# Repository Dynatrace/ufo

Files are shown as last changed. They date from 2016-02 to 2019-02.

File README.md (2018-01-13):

# UFO
### Visual alert/status display for builds, CI, continuous delivery, operations, and more 
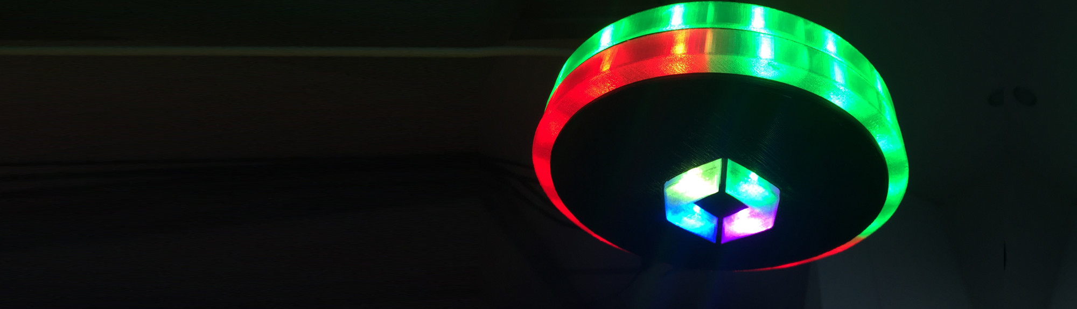
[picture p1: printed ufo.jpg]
printed ufo


* Easy to print, build and 
* Fosters collaboration when placing in areas like office cafeteria, ...
* Open source hard- and software
* WiFi
* REST api, control 34 RGB LEDs
* Integrates with CI/CD/Monitoring (e.g. Jenkins, Nagios, Cloud-Watch, Dynatrace, ...) 
* Easy to modify, Arduino compatible ESP8266 microcontroller 
***

* [__Story__](story) The original UFO was created by Helmut, Dynatrace Chief Software Architect. Read his story.  
* [__QuickStart__](quickstart) Quick guide to configuring the UFO
* [__How to__](howto) Step-by-step instructions for building your own UFO
* [__Parts list__](partlist/readme.md#ufo-partlist)
(folder must use this name for Arduino IDE to automatically upload to ESP8266)
* [__3D printing__](3dprint) folder contains all CAD files plus derivative 3D print files
* [__UFO.ino__](ufo.ino) is the Arduino IDE main program: requires Arduino IDE 1.6.7+ plus additional modules. see ufo.ino source file for more details about requirements
* [__Data__](data) folder contains all files that will be loaded into the ESP8266 flash memory SPIFF drive to contain website data 
* [__Node.js test server__](testserver) contains source files to simulate the ESP8266 webserver for testing purposes; requires Node.js server + static-server module

## No time to print yourself? [Buy a 2nd Gen UFO now](https://www.dynatrace.com/solutions/devops/ufo/get/)

### Example use case at Dynatrace Ruxit
The UFO visualizes the actual continuous delivery pipeline, from developers commit to the build system, all the way to deployments into staging systems. The UFO visualizes two pipeline stages, and for each it uses different color/animation coding to represent states and severity. Of course you can assign your own meanings to the visualization and even customize the UFO and APIs to your needs.
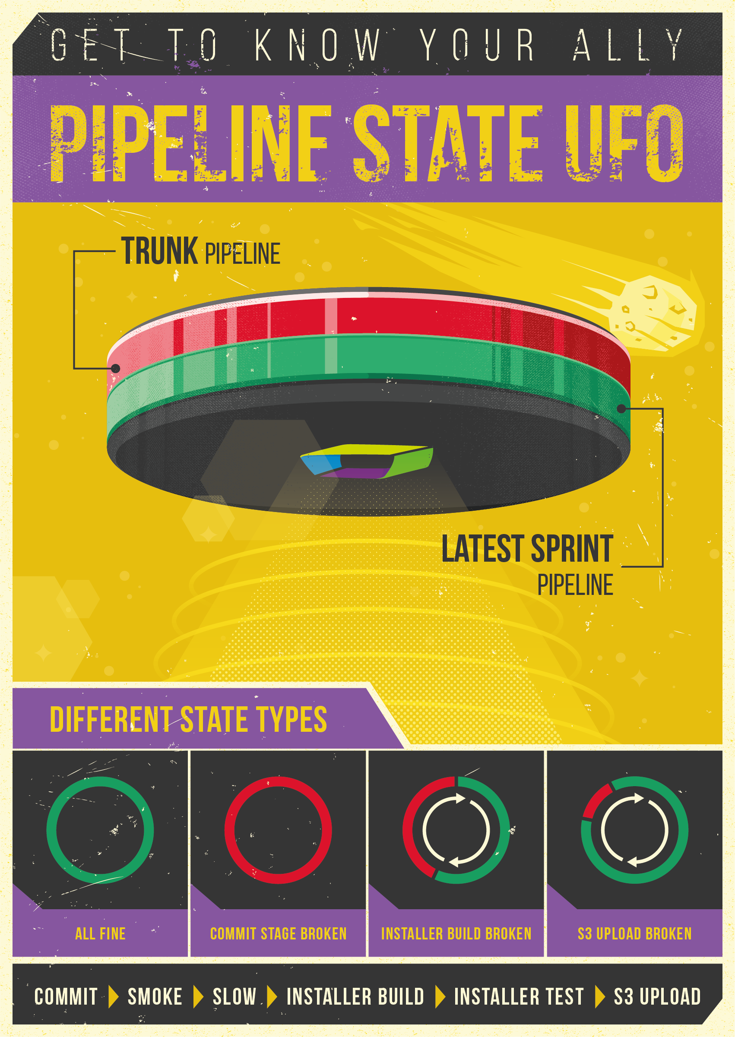
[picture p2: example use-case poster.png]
ufo banner


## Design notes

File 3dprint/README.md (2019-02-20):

# 3D Print your own UFO

You can print your own UFO. All you need to do is order an Adafruit Huzzah, some wires, and print the UFO in black and transparent filament. The Huzzahs ESP8266 hosts wifi and a web server so that REST calls plus a simple hybrid web app are used to configure and control the device.

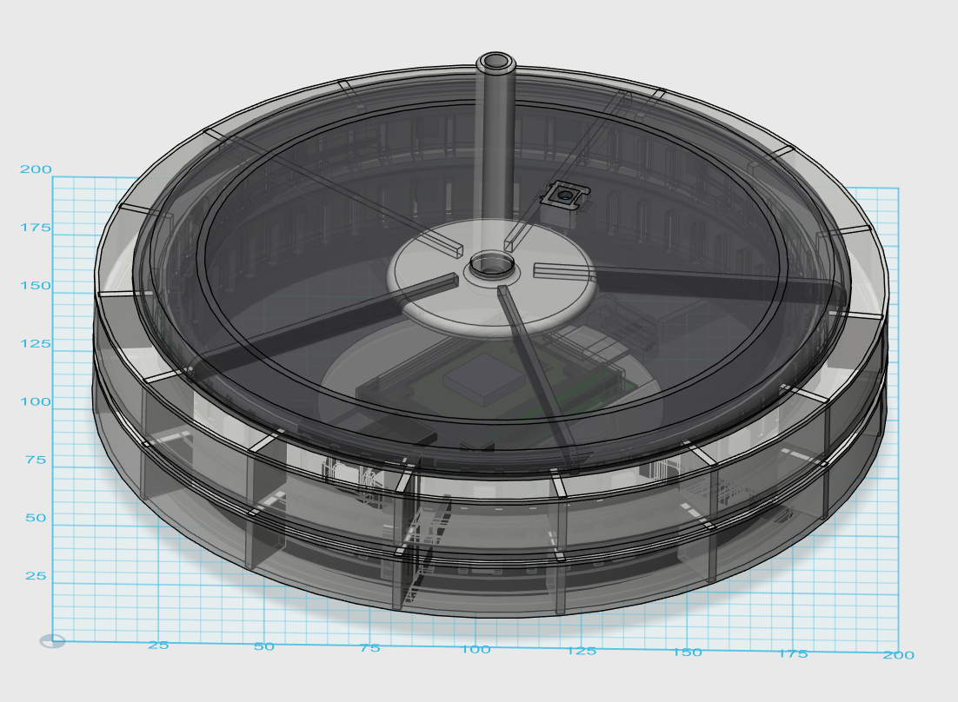
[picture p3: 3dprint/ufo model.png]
UFO model for 3D print


Prints have been tested so far with:
* Makerbot replicator 5th generation
* Ultimaker 2+ (coming soon)

Useful 3D Print guide:
http://www.matterhackers.com/articles/how-to-succeed-when-printing-in-pla

<strong>LIMITED SUPPORT & WARRANTY FOR THE OPEN-SOURCE VERSION OF THE DYNATRACE UFO</strong>

Dynatrace doesn’t provide support, a warranty, or firmware updates for the 3D-printable open-source version of the UFO.

<strong>For all hardware and software support issues</strong>, <a href="https://github.com/Dynatrace/ufo/issues">raise an issue on our GitHub site</a>.

<strong>Firmware updates provided by our user community</strong> are available for <a href="https://github.com/Dynatrace/ufo/tree/master/firmware">download from Github</a>.

DYNATRACE MAKES NO WARRANTY WHATSOEVER WITH RESPECT TO THE GOODS, INCLUDING ANY (A) WARRANTY OF MERCHANTABILITY; (B) WARRANTY OF FITNESS FOR A PARTICULAR PURPOSE; (C) WARRANTY OF TITLE; OR (D) WARRANTY AGAINST INFRINGEMENT OF INTELLECTUAL PROPERTY RIGHTS OF A THIRD PARTY, WHETHER EXPRESS OR IMPLIED BY LAW, COURSE OF DEALING, COURSE OF PERFORMANCE, USAGE OF TRADE OR OTHERWISE.

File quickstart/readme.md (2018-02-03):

# UFO Quickstart

## Power Supply

Connect the UFO to a 2000mA USB charging adapter.
e.g. the iPad or Windows Surface charger should work fine, but check the specs beforehand.
Note that the UFO draws more current than standard USB can provide.
Please be warned! Also note that the USB cable is for power only,
there is no data-connection through it.

The intended use is pendant mounted at the ceiling.
But some geeks use it mobile, so they take it into their office park for example.
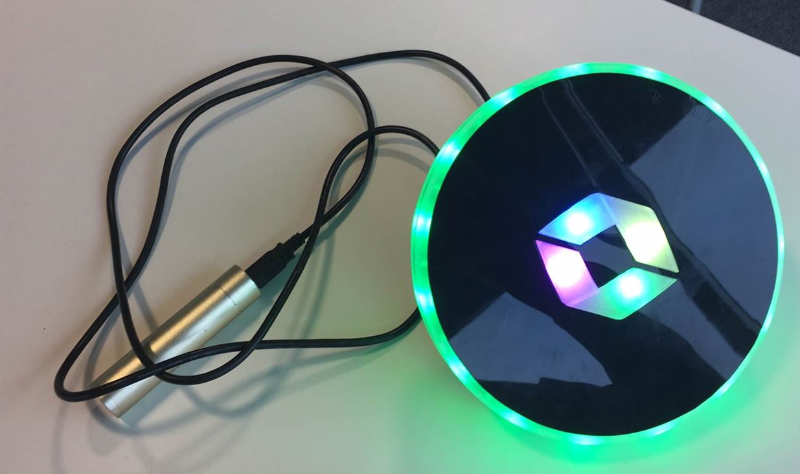
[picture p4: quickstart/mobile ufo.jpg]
mobile ufo


## Check Firmware Version

This description is for [firmware](../firmware) versions dated after 20th of October 2016.
If you have older firmware, please follow the firmware updated procedures in the howto guide.

## Configure Wifi

1. As default and when clicking the hardware reset button at the top of the UFO,
the UFO starts a Wifi access point with an SSID named "ufo".
(if you cannot see the "ufo" SSID, click the wifi reset button) -
the UFO alternates a single blue ring

2. Connect a Web browser enabled device (laptop, tablet, smartphone)
to the UFO's Wifi with the SSID "ufo" and navigate to [http://192.168.4.1](http://192.168.4.1) -
Once connected the UFO blinks with a second blue ring

3. Configure UFO wifi settings so that the UFO connects to your wifi
(Note: WPA2 works well, but enterprise WPA2 and PEAP authentication is not yet available) -
whenever the UFO is trying to connect to your wifi, the UFO blinks yellow.
So you can declare connection success when the yellow stops blinking.

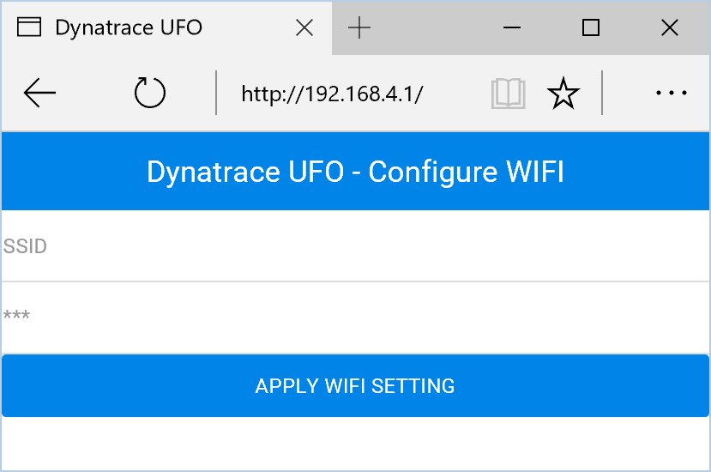
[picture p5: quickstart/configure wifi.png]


Note: If you have troubles using the web UI for setting the wifi config,
you might have more success using the REST API directly:
`http://192.168.4.1/api?ssid=<ssid>&pwd=<pwd>`

Tip: To test and play with the ufo despite enterprise wifi,
or in situations that require a wifi login, you can use following workaround:
e.g. Windows 10 (anniversary update) mobile hotspot feature or connect it your mobile devices hotspot capability.
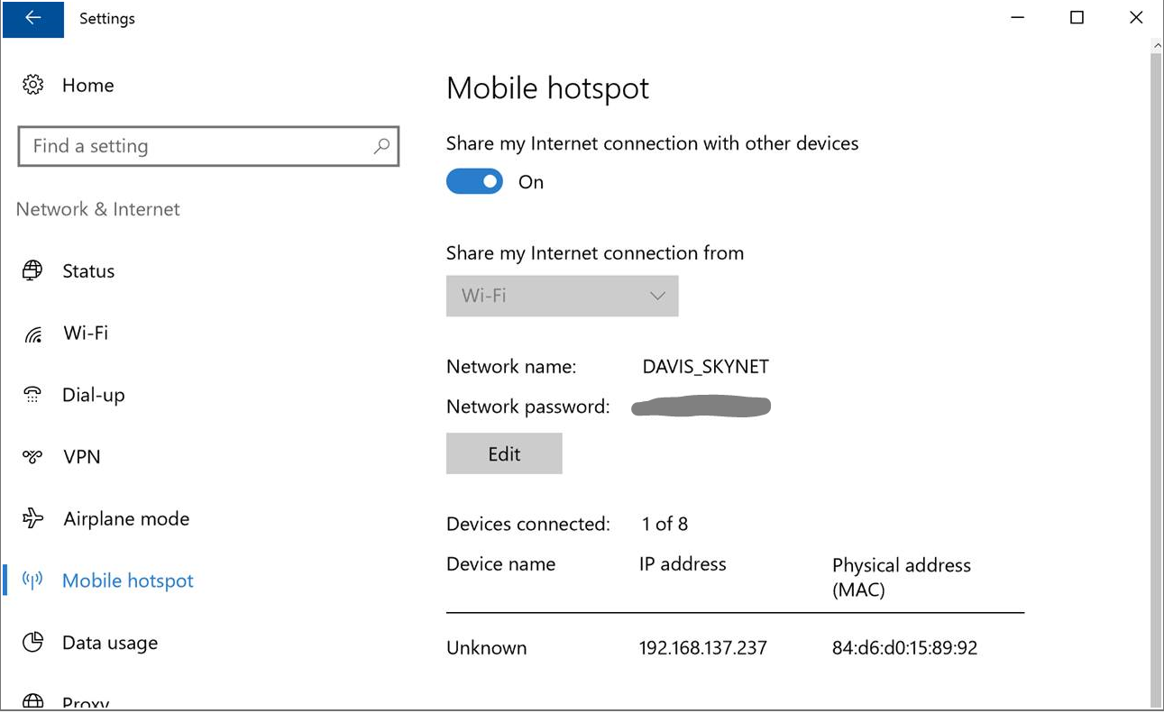
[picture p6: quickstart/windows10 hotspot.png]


1. The UFO will reboot after you configured its Wifi and start to blink
yellow while trying to connect and show color encoded IP address when connected.
At that point you might be able to connect to it with [http://ufo](http://ufo)
as the UFO registers with a default hostname of "UFO"
with the DHCP server.

If that doesnt work you will need to use `http://<ipaddress>`.

There are multiple ways to discover the IP address of the Dynatrace UFO
in case you need it:
  1. Option: the UFO is displaying the address color coded until you access
  it the first time.
  The lower ring visualizes the current IP address digit by digit.
  192.168... will light 1 led then 9 (shown as 5+4 LEDs) then 2 and so on.
  A dot is visualized as 3 white leds.
  The individual digits are separated by a short white flash.
  The IP is visualized over and over again until the first api rest
  call is issued. To stay in sync every IP address visualization
  run uses a different color.
  1. Option: In case you used Windows 10 hotspot,
  you will find the IP address right there.
  1. Option: lookup the MAC address in your Wifi Access Point
 and get the IP address assigned by DHCP.

## Integration with Dynatrace SaaS

The Dynatrace UFO polls the Dynatrace SaaS problem status using HTTPS.
For that you need to create in the Dynatrace SaaS user interface
an access token. (and please don't try to use the token in the screenshot,
its of course an invalid one).
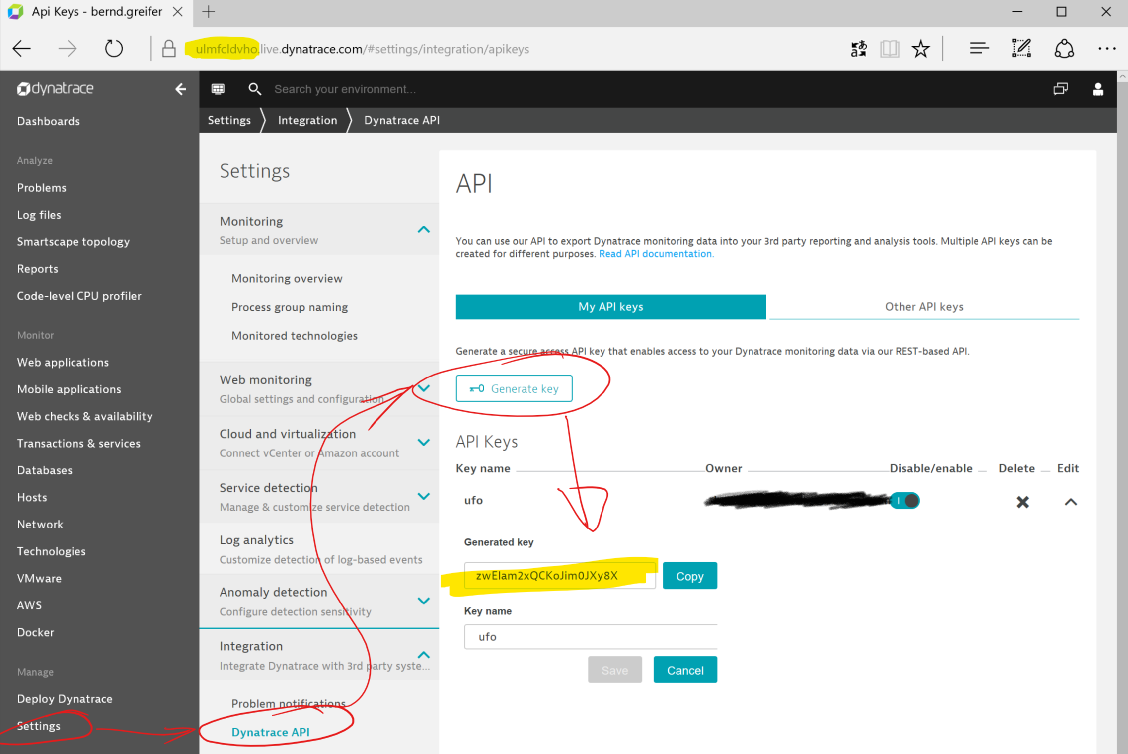
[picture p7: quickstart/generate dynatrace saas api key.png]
generate%20api%20token


Dynatrace SaaS default integration shows currently following color codes
* green: no open problem
* all red: 1 open problem affecting end users
* all purple: 1 open problem affecting services
* all blue: 1 open problem affecting infrastructure only
* 2 or 3 red segments rotating:
2, 3 or more opten problems affecting end users
* 2 or 3 red purple rotating:
1 open problem affecting services.
* 2 or 3 red blue rotating:
1 open problem affecting infrastructure only
* mixtures of above, where use impact where severity is in the order of
user impact, services, infrastructure

This is how it looks when it is connected and showing a problem:
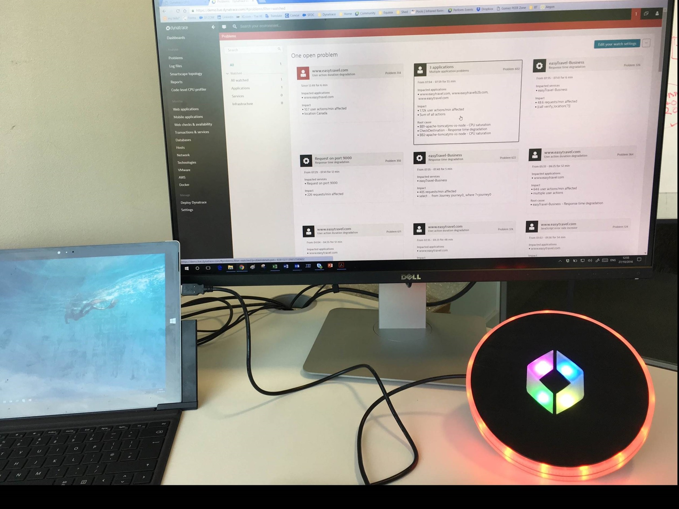
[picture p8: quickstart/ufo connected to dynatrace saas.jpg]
Ufo%20alerting%20of%20live%20problem


## Integration with Dynatrace Managed

Coming soon. This will use webhooks.
Please use the Generic REST interface for now.

## Integration with Dynatrace AppMon

Coming soon. Please use the Generic REST interface for now.

## Generic REST Integration

The UFO's REST API is well documented in [a Dynatrace blog post (Step #2: Using the REST API)](https://www.dynatrace.com/blog/using-dynatrace-devops-pipeline-state-ufo/). However, here are some UFO communication examples (REST calls):

GET `http://<ipaddress>/api?top_init=1&top=0|3|FF0000&top_bg=00FF00`

GET `http://<ipaddress>/api?top_init=1&top=0|1|FFC000|1|3|FF0000|4|1|FFC000&top_bg=00A00a&top_whirl=220`

GET `http://<ipaddress>/api?bottom_init=1&bottom=0|15|FF0000&bottom_bg=0000FF&bottom_morph=500|6`

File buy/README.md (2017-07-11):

# Buy?
If you would prefer to buy a Dynatrace UFO versus build it yourself, 
then you can buy it here:

https://www.dynatrace.com/solutions/devops/ufo/get/
please note that this includes the more powerful ESP32 microcontroller, dual-core with Wifi and bluetooth.

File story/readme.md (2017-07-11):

# The Dynatrace UFO story

*Bernd:* Hi Helmut, you have invented the UFO, a multidimensional state visualization device, for Dynatrace to improve our agile development, build and continuous delivery processes. 
So what exactly is the UFO and what motivated you to create it?

__Helmut:__ I created the UFO because we had a lack of awareness of build problems in our CI process. 
It often happened that developers broke the pipeline without realizing it. Without knowing that they'd introduced a problem into the pipeline they had no reason to consider that their recent changes might be the cause of a problem. 
Installing this visualization device in our cafeteria made a big change in our developers' awareness of build failures, and also in their mindset. Pipeline errors need to be avoided at all cost – you don’t want to be the one who floods the cafeteria with red light.

So generally stated, the UFO is a general state visualization device. The requirement to function from any view angle gave it its distinctive UFO design. It consists of 2 layers that emit light with customizable color and animation. For us, it provides real-time feedback on our build and continuous delivery process to keep the team in sync and responsible.

*Bernd:* How did it change the behavior of the team?

__Helmut__: The team has become more sensitive to checking the UFO before going home. When the UFO goes red in the cafeteria, devs who recently checked in code now double-check the build results and their inbox where issues are routed to. 

*Bernd:* As our team has hundreds of engineers, one can impact many, right? 

__Helmut:__ Build failures and consequently the red state of the build pipeline not only block all developers from committing their changes but it also delays the build entering the various automated test-stages. This slows down the overall development process and diminishes our productivity.

A fast pipeline is especially crucial in our DevOps environment as we require that potential fixes be brought into production as quickly as possible. Optimal utilization of automated test-resources is an important factor for us, as well.

*Bernd:* The UFO, with its more than 34 individual controllable RGB LEDs, is more powerful than a classic "red alert" lamp. So how is it integrated with the continuous delivery process?

__Helmut:__ The UFO is directly fed with the pipeline state by our quickbuild server at the end of every run via a simple REST interface. One layer of the UFO visualizes the trunk pipeline while the other shows the sprint pipeline state. The DevOps team controls the UFO using Dynatrace Application Monitoring / UEM and Ruxit interfaces. But of course, you can control it from any software capable of performing REST calls.

*Bernd:* We had several top customers who came to our office ask for such an UFO. Since you have built it yourself, what can we tell customers who want to build one themselves? Here are pictures of the original so everyone can see what I am talking about:
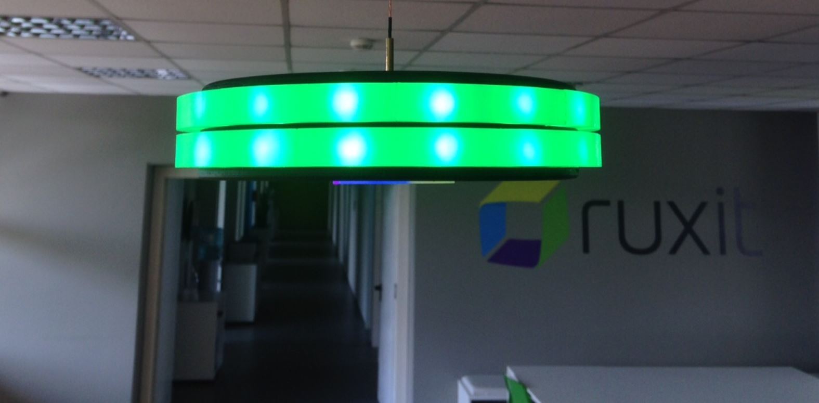
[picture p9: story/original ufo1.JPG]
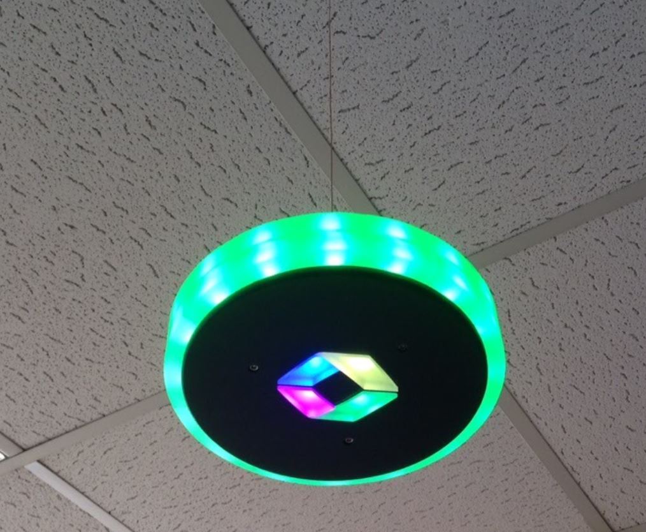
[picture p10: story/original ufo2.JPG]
 

__Helmut:__ Oh, yes. The original version used Raspberry PI and multiple PIC microcontrollers that I'd used in plenty of other projects. To reduce the total number of parts, we designed an open-source version of the UFO that is easily printable on a standard 3D printer and a single ESP8266 wifi microcontroller. The total cost is in the range of $80 including the wifi-enabled electronics. It's available at https://github.com/Dynatrace/ufo

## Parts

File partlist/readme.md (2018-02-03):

# UFO partlist

## Approximate cost per UFO
* $5 filament (filament spools cost $20 to $65, and you need two colors)
 * black PLA filament
 * transparent PLA filament
* $35 for microcontroller, USB cable, switch and wires
* $10 for 2000mA USB charging device to power the UFO

## What you'll need
* 3D printer capable of printing volume L19cm x W19cm x H12cm minimum
* soldering iron, wires
* FTDI cable (approx $15) for programming the ESP8266

## Places to look for the electronics
* U.S.: Adafruit <http://www.adafruit.com>
* U.S./Internationally: Mouser electronics <http://mouser.com> (they have many international sites such as mouser.de, mouser.at, ...)
* Germany/Austria: Flikto <http://flikto.de>
* Germany/Internationally: EXP Tech <https://www.exp-tech.de/>

## Electronics partlist
* 1x [Adafruit Huzzah ESP8266 breakoutboard](https://www.adafruit.com/products/2471) 
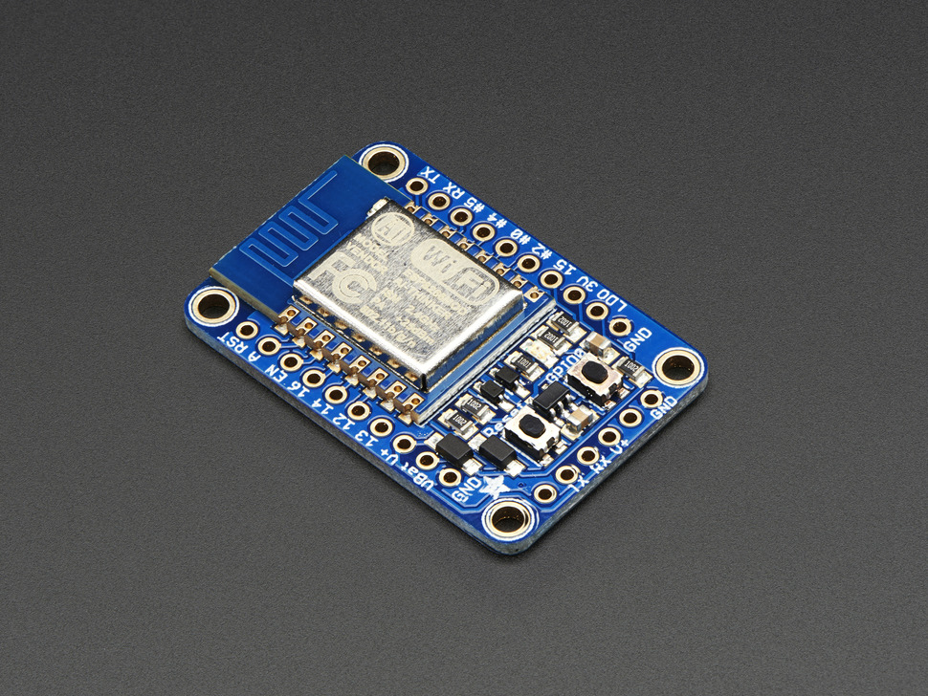
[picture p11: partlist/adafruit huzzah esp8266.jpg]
Adafruit Huzzah breakout board

* 2x meters [Adafruit DotStar Digital LED Strip, 30 LED per meter](https://www.adafruit.com/products/2237)
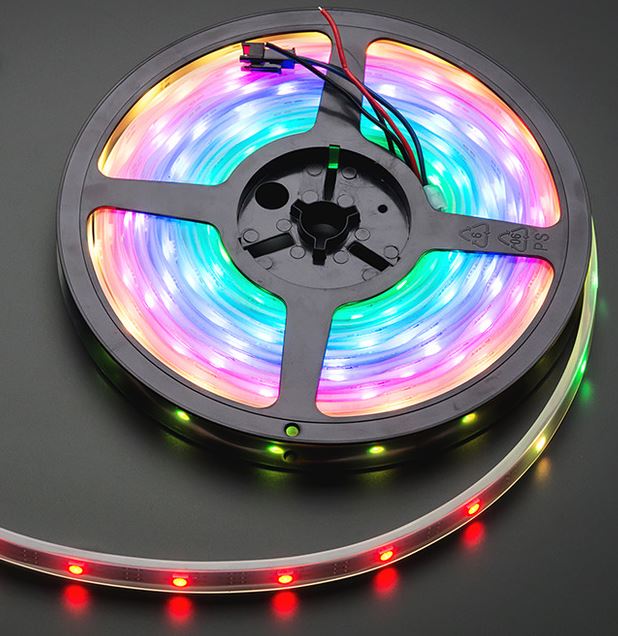
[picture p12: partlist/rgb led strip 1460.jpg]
LED strips 800MHz

* 1x [mini-push-button-switch 6x6mm](https://www.sparkfun.com/products/97)   
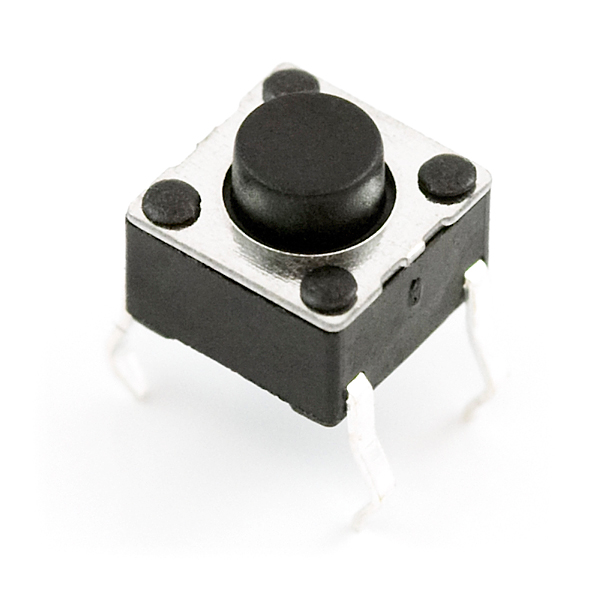
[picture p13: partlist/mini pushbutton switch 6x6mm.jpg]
mini pushbutton switch
 
* 1x [USB cable to power the ufo] e.g. (https://www.sparkfun.com/products/512) but note, the cable must be able to handle the current of up to 2A; and we will clip off one of the plugs 
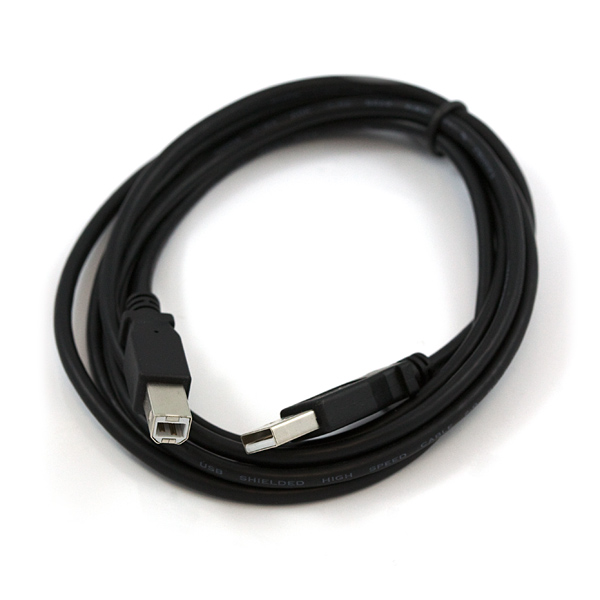
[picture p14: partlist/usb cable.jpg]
USB cable

* If you don't have it yet, you will need this cable for programming [Sparkfun FTDI 5V with 3.3V IO cable](https://www.sparkfun.com/products/9717) 
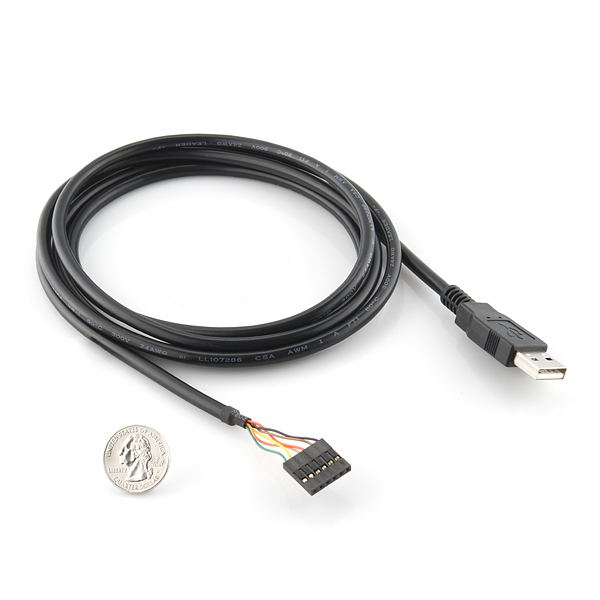
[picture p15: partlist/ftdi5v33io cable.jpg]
FTDI cable


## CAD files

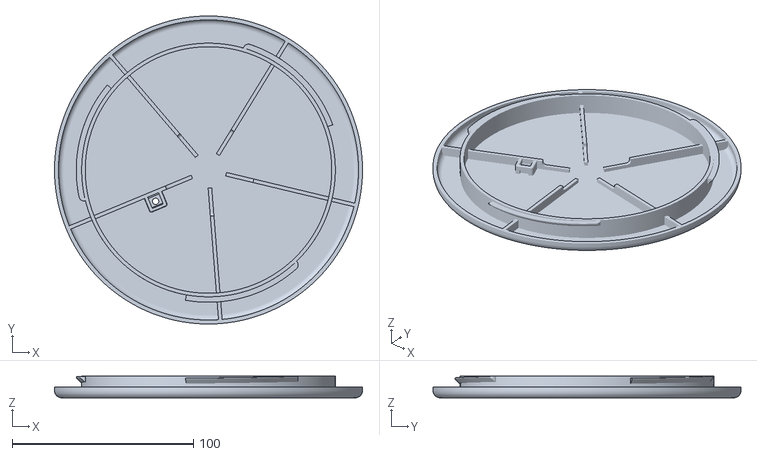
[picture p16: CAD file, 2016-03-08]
3dprint/printfiles v3/top.stl
170.0 x 170.0 x 12.0

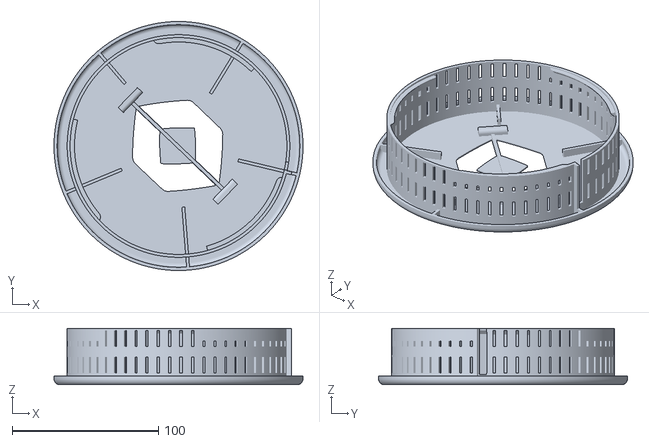
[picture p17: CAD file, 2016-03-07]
3dprint/printfiles v3/bottombuildup.stl
170.0 x 170.0 x 38.5

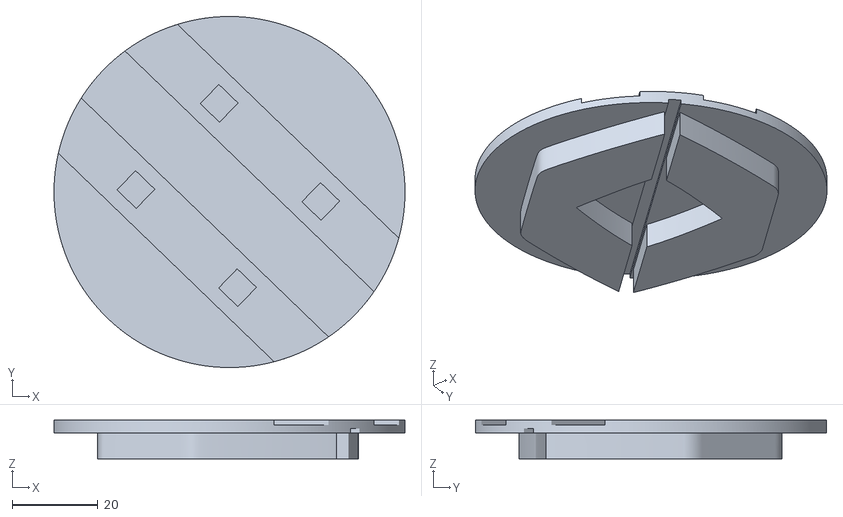
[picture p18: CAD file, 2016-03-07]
3dprint/printfiles v3/downlight inlay.stl
82.0 x 82.0 x 9.02

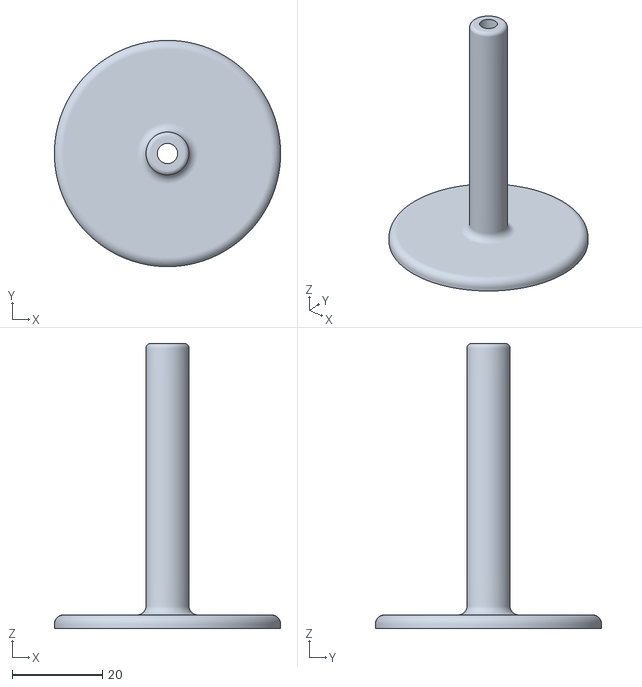
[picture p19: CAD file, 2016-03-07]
3dprint/printfiles v3/cablestabilizer 4.5mm.stl
50.0 x 50.0 x 63.0

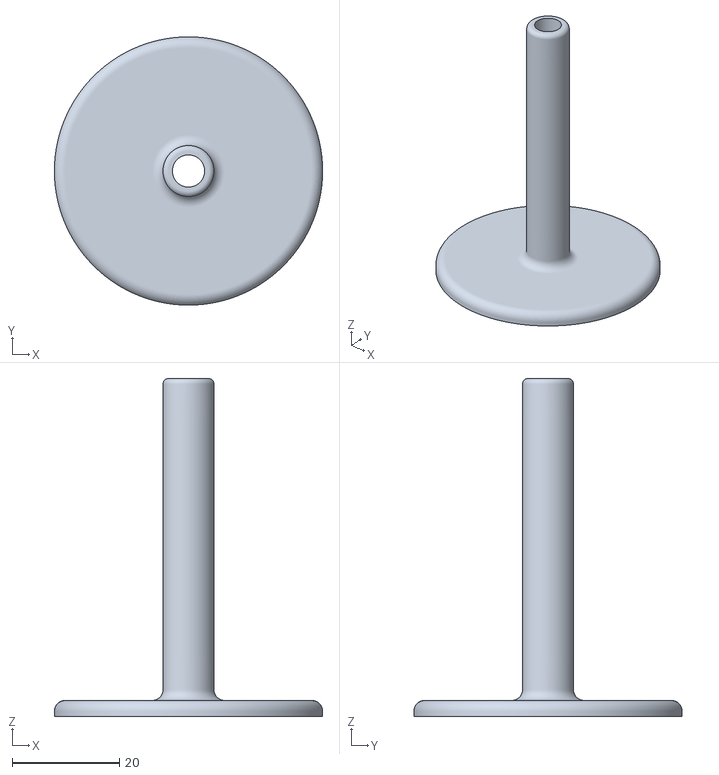
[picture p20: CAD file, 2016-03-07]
3dprint/printfiles v3/cablestabilizer 6.0mm.stl
50.0 x 50.0 x 63.0

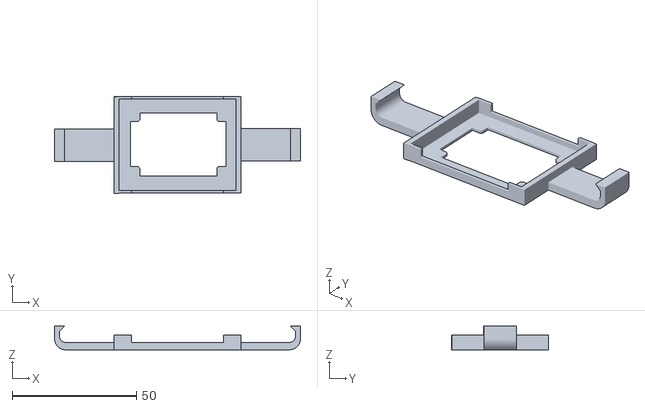
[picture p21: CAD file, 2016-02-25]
3dprint/printfiles v3/huzzahclip.stl
99.0 x 39.2 x 9.50

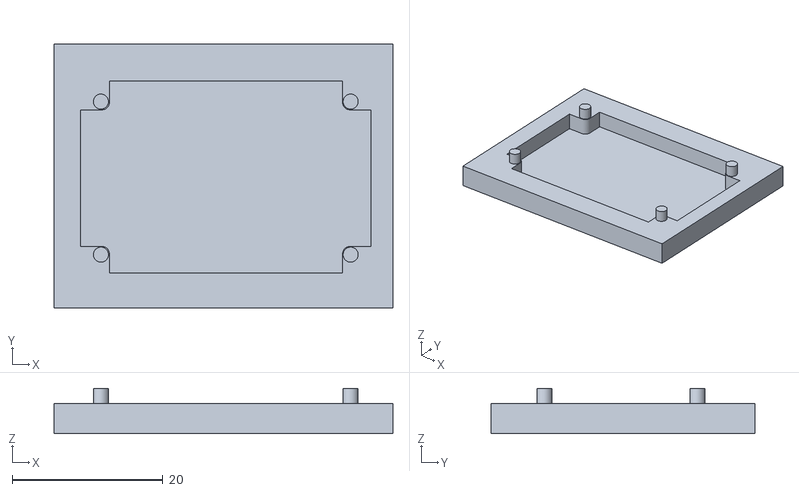
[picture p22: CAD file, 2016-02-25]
3dprint/printfiles v3/huzzahbase.stl
45.0 x 35.0 x 6.00

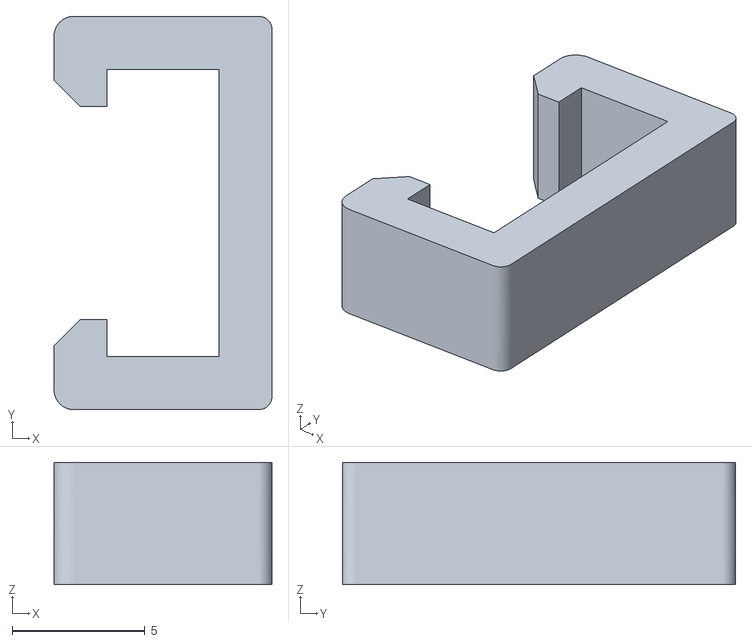
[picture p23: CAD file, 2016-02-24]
3dprint/printfiles v3/minibuttonclip.stl
8.20 x 14.8 x 4.60

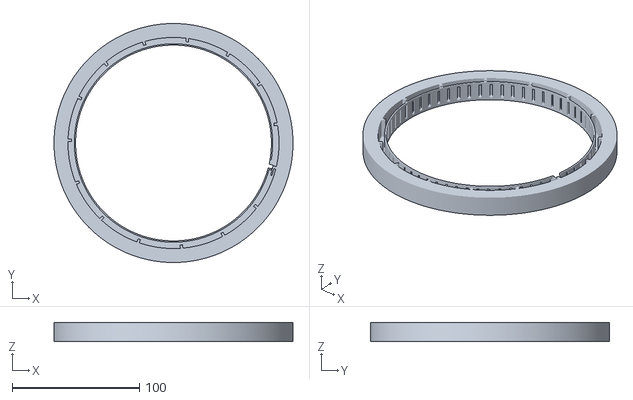
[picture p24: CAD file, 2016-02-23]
3dprint/printfiles v3/ledring.stl
188.0 x 188.0 x 15.0

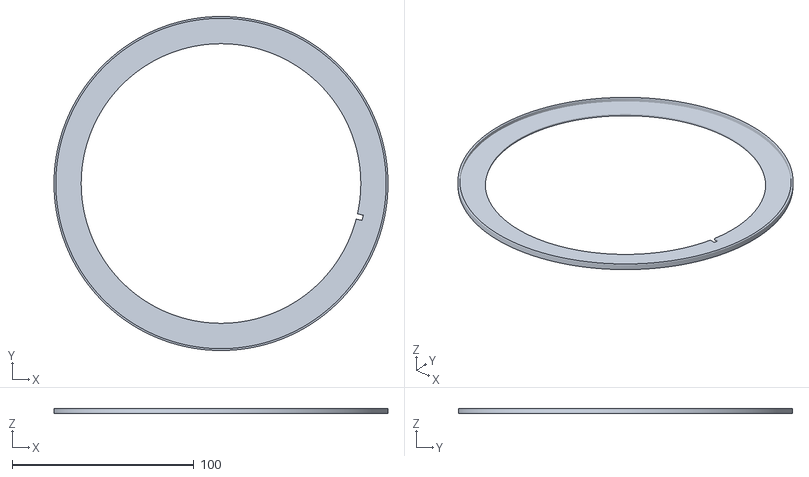
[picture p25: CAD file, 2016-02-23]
3dprint/printfiles v3/separatorring.stl
184.0 x 184.0 x 3.00

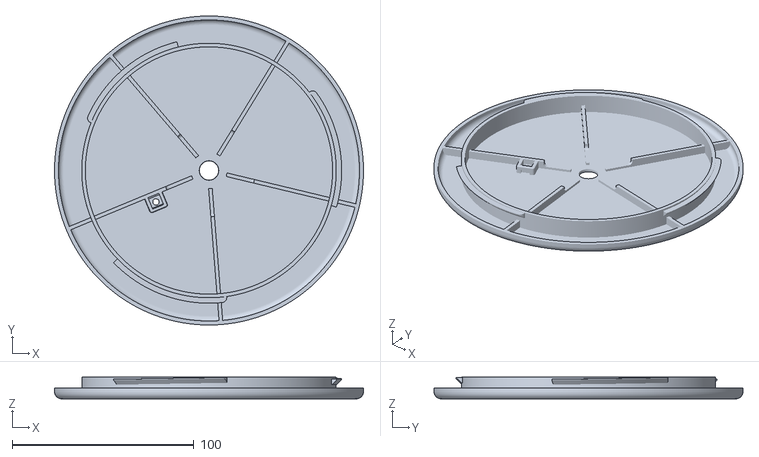
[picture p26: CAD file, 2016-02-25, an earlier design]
3dprint/printfiles v2/top.stl
170.0 x 170.0 x 12.0

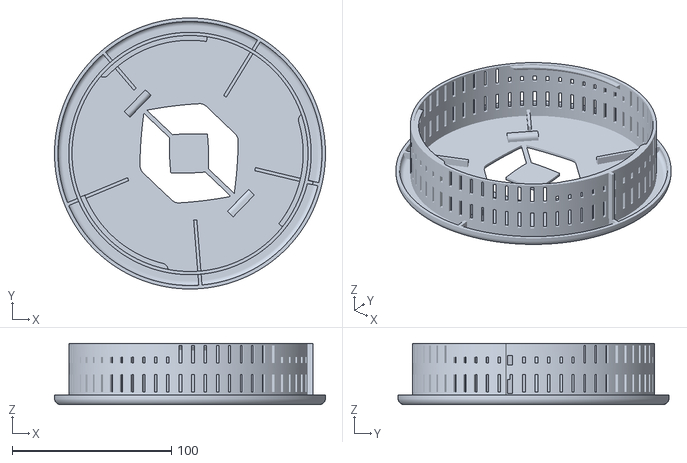
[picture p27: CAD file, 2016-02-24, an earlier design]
3dprint/printfiles v2/bottombuildup.stl
170.0 x 170.0 x 38.5

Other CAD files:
3dprint/printfiles v3/cablestabilizer 5.0mm.stl
3dprint/printfiles v2/downlightinlay.stl
3dprint/printfiles v2/cablestabilizer.stl

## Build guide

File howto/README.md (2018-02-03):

# Instructions for building the Dynatrace UFO

see also [partlist](../partlist)

## Print the 10 pieces in 5 batches

#### We printed using with following settings:
* No supports
* 3 shells
* 0.2 mm layer height (0.1 mm layer worked well too)
* 20% infill

#### 1. UFO case base + microcontroller holder, plus microcontroller clip

black filament
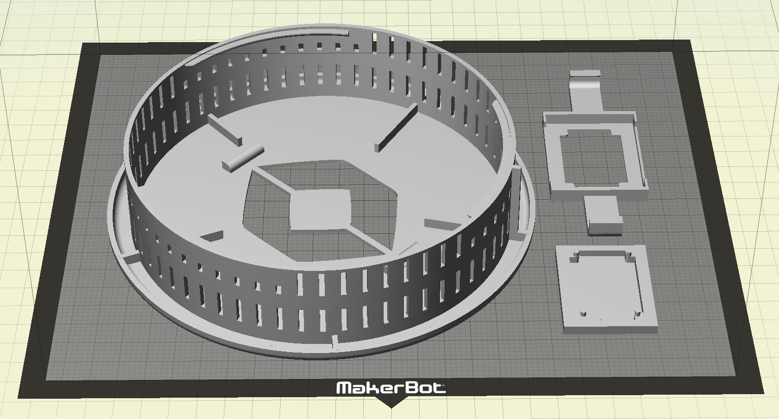
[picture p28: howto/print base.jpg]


#### 2. UFO case top + cable stabilizer + mini-switch-clip

black filament
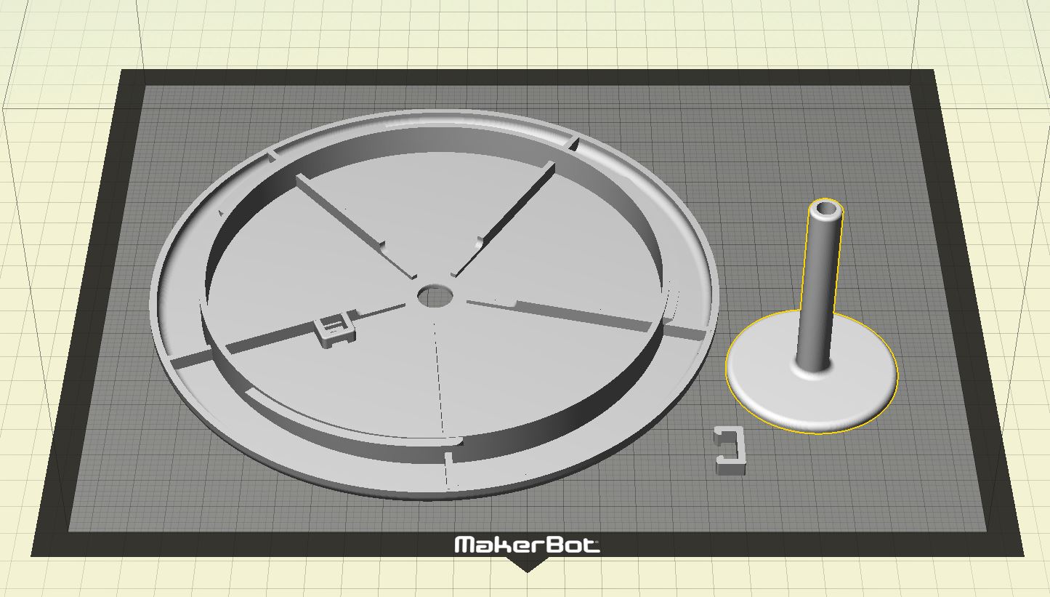
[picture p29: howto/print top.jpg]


#### 3. Separator ring

black filament
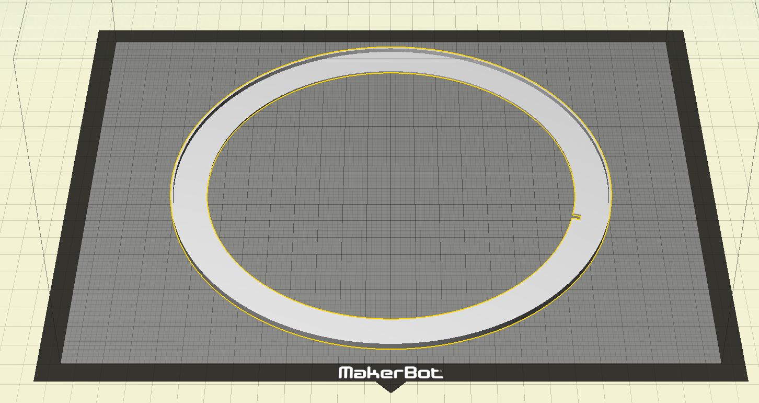
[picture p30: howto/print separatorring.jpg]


#### 4. Downlight inlay + first ring

transparent filament
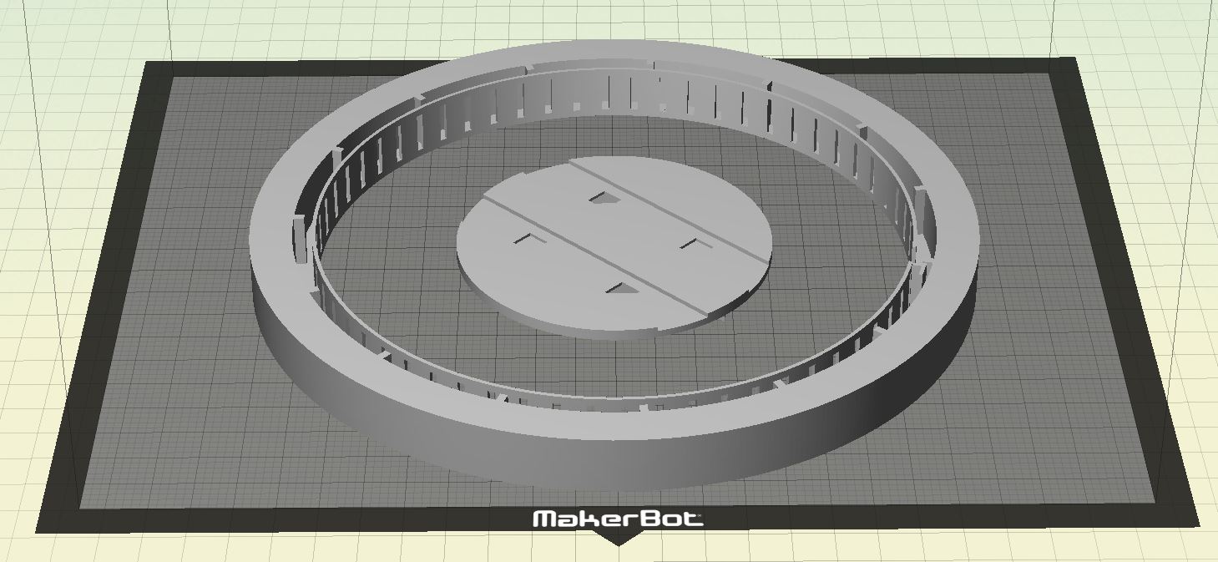
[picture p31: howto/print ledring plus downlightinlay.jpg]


#### 5. Second ring

transparent filament
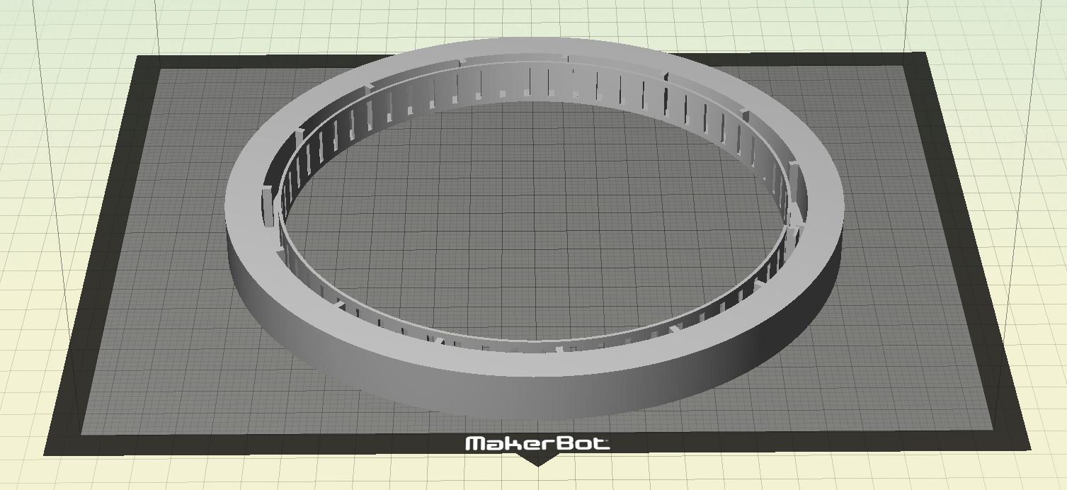
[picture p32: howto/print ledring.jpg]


##  How it all fits together
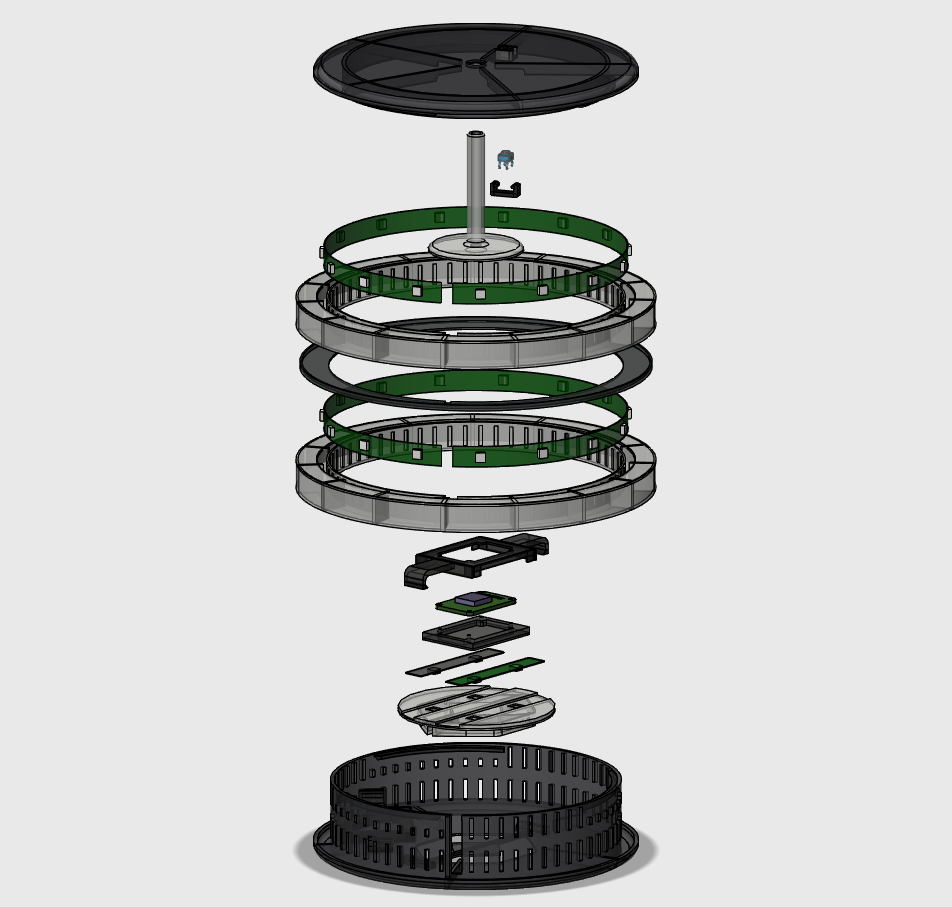
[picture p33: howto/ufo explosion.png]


## Prepare USB cable
Cut off one end of the USB cable and use the 5V line (red) and ground (black) wire for powering the LED strips as well as the Huzzah ESP8266 microcontroller. Make sure to isolate the other wires to make sure you don't damage the USB source or get in contact with the other electronics.
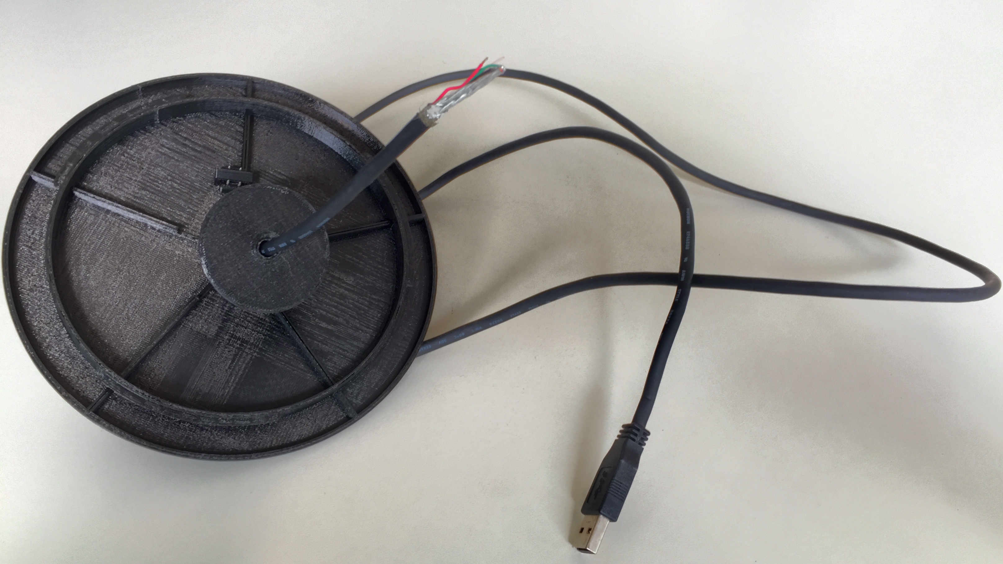
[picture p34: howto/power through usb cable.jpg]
Power through USB cable


## Prepare LED strips
Cut the LED strip into 2 strips of 15 LEDs each and 2 strips of 2 LEDs each. Be sure to cut exactly in the middle of the soldering tabs because you will need to solder cables together here later.
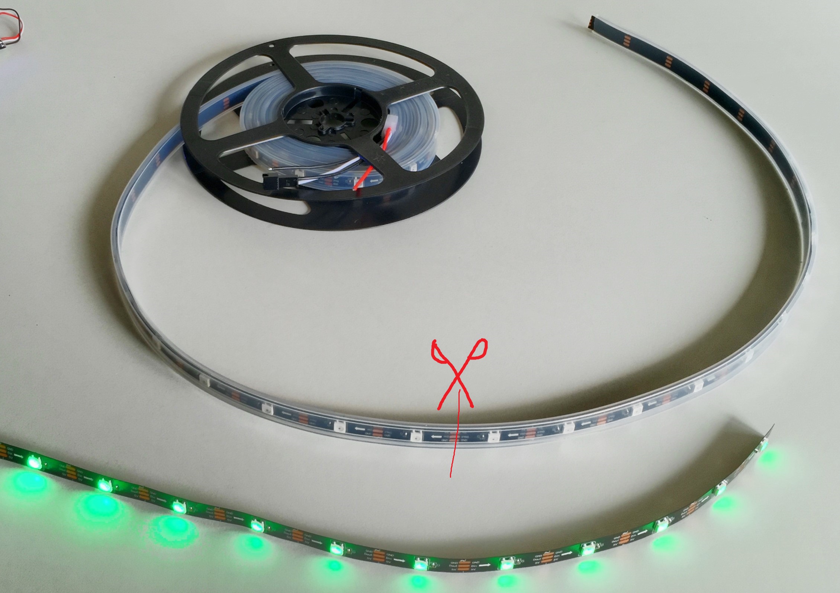
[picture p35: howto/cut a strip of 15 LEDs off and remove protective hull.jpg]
Cut the LED strip in pieces

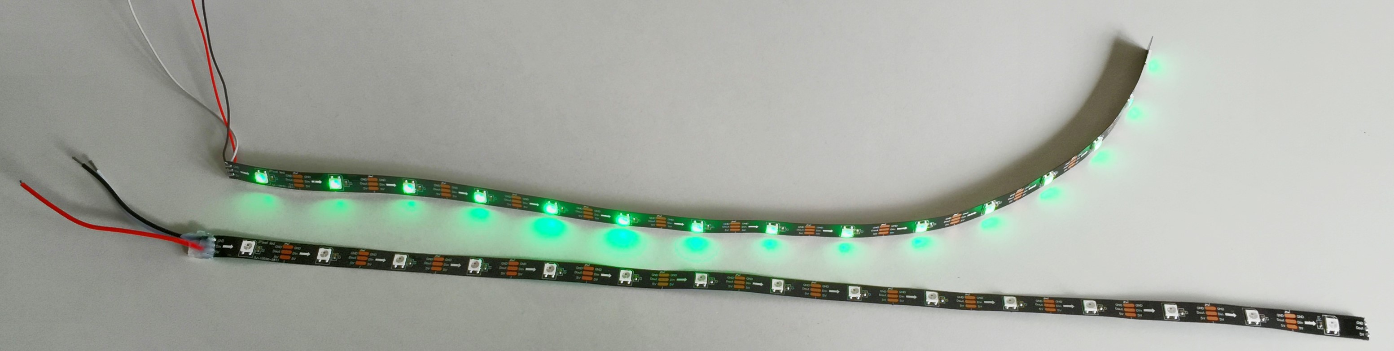
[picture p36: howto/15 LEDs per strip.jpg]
15 LEDs per long strip


## Solder short strips
Solder the short strips in a series accordingly to the data-flow direction. There are arrows on the strip that show you the direction. Data for controlling the bus of LEDs flows from the microcontroller outbound in direction of arrow.
(Note: image still shows 3-pin led strip, but we switched to 4-pin DotStar LED strips)
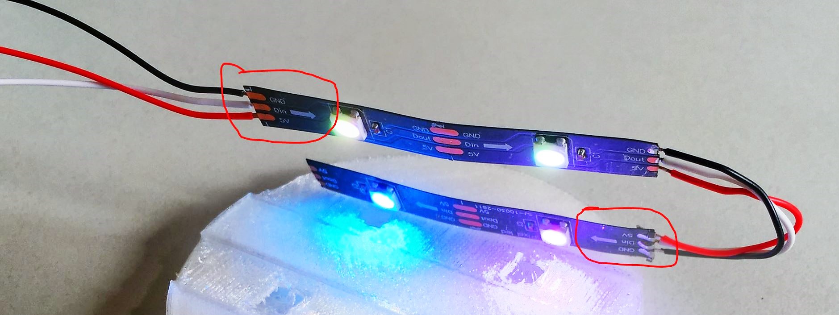
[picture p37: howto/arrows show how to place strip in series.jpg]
Short LED strips soldered in series

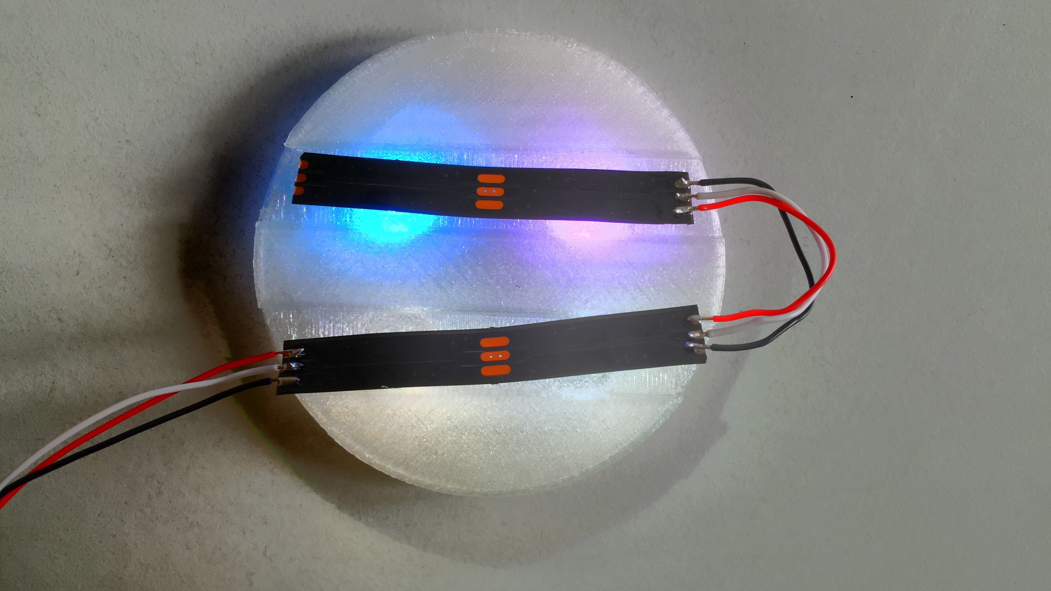
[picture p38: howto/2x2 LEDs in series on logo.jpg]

The DotStar LED strips use 4 wires
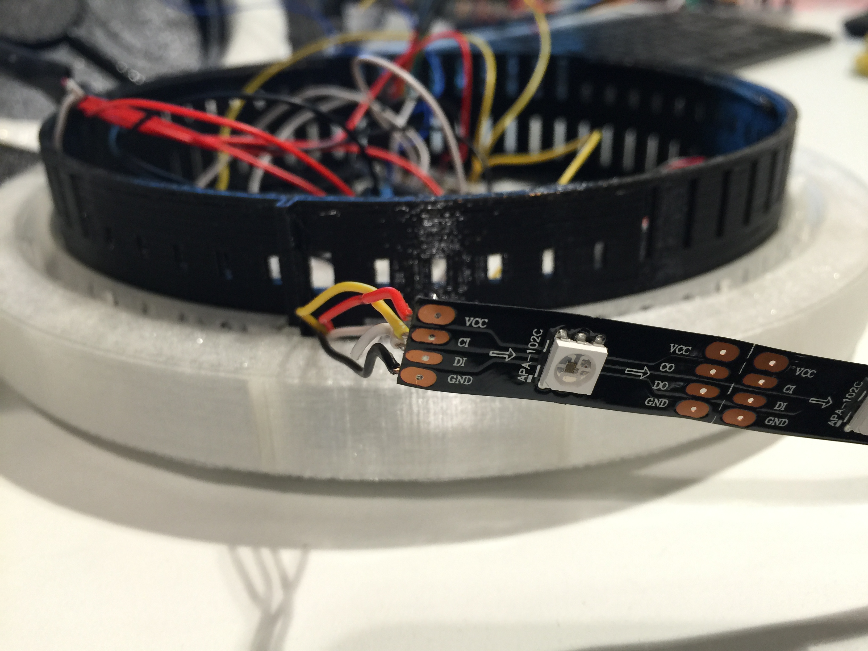
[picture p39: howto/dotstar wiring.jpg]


## Wiring
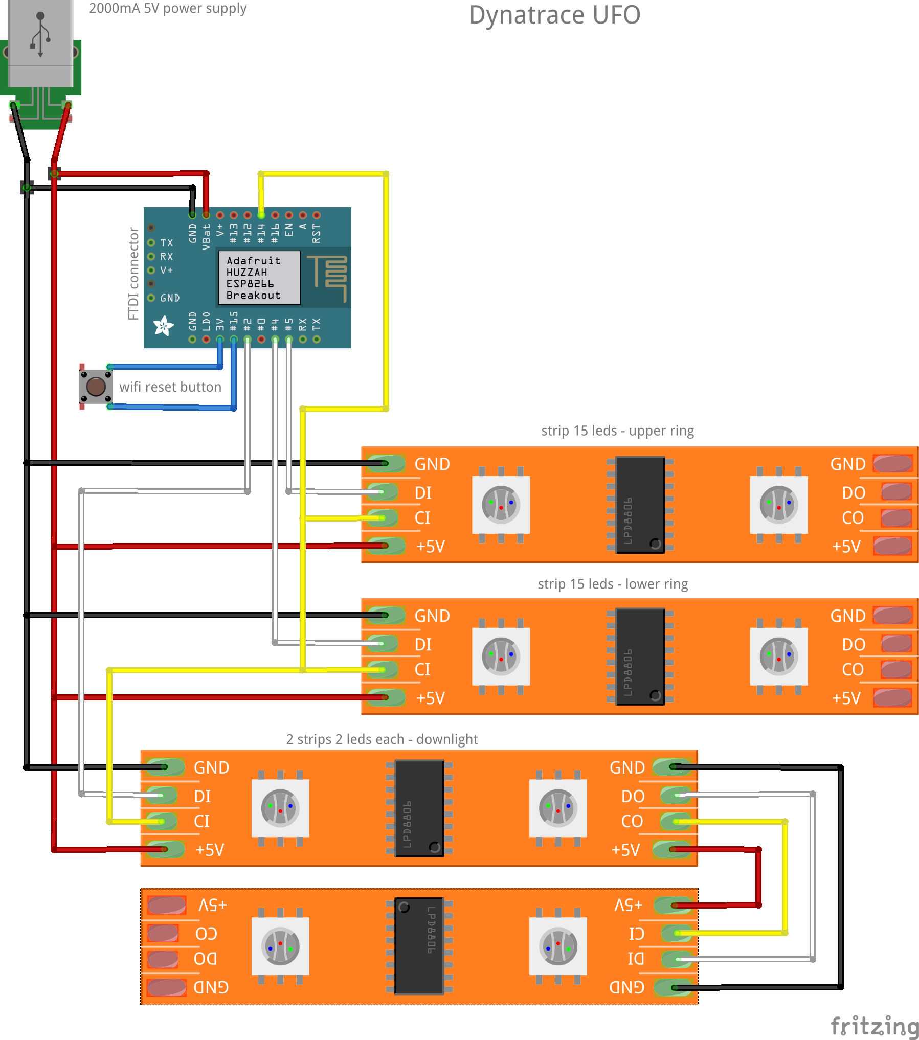
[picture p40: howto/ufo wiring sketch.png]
Wiring


USB cables 5V power goes to "VBat" and the black ground cable goes to "GND"
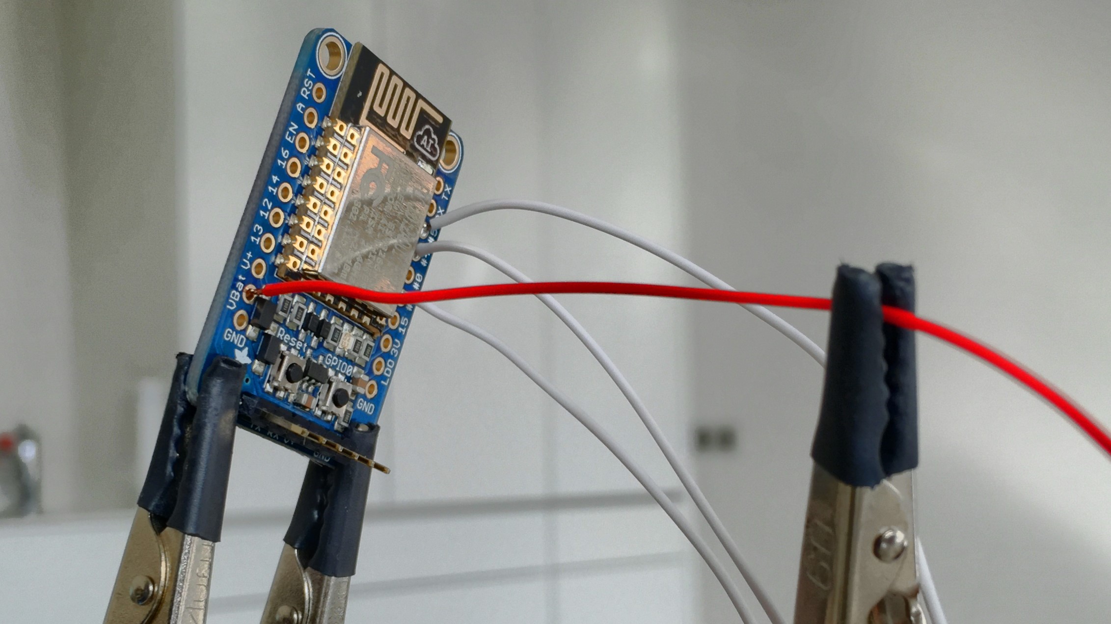
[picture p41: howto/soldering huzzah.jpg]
soldering power to huzzah


The white data wires that control the LEDs are soldered as follows:
* Pin 4 - Lower LED ring
* Pin 5 - Upper LED ring
* Pin 2 - Downlight LEDs

The yellow cable is the clock signal for the LED strips
* Pin 14 - DotStar LED clock - connects to all three LED strips

The blue wifi reset cables:
* Pin 15 - Mini-button-switch for wifi reset, to switch the UFO into Access Point mode; triggers when 3V are on pin 15
* Pin 3V (next to pin 15) - Goes to the other contact of the mini-button-switch.

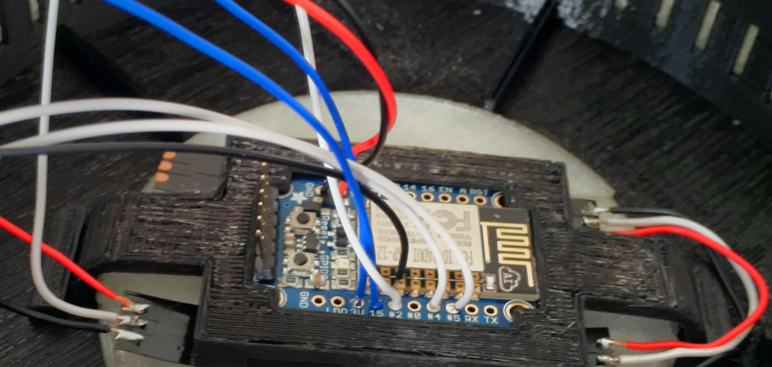
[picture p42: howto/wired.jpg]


Note that the LEDs need to be powered directly from the USB cable, and not from the 3V pin. So all the red 5V cables and separately all the black ground cables must be soldered together.

## Putting it all together
The Huzzah ESP8266 microcontroller is mounted on top of the downlight inlay and also keeps the 2 short LED strips in their position. For proper isolation, put the printed platform with the 4 pins upside under the Huzzah board and then put all of it inside the clip that holds everything in place.
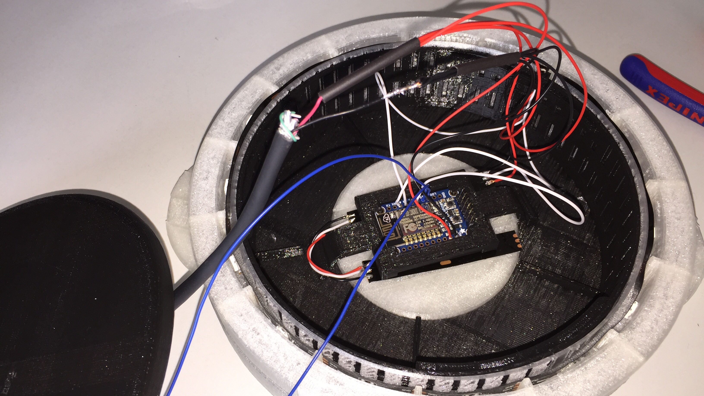
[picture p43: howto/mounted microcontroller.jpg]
clip-in microcontroller


## Firmware
The initial firmware needs to be programmed using the Serial-USB (FTDI) cable.
You might need to install a driver on your PC for that cable.
Once you have that completed, you can use the UFO web UI to upload the firmware.

### Upload firmware available on github
1. Connect the ESP8266 to the FTDI cable and via USB to your computer
1. Place the ESP8266 in firmware programming mode by pressing the buttons in the following sequence:
  * Press and hold Reset
  * Press GPIO0. You should see the red LED turn on
  * Release reset
  * Release GPIO0 and make sure the red LED is still lit, as it's signaling that the ESP8266 expects a firmware download

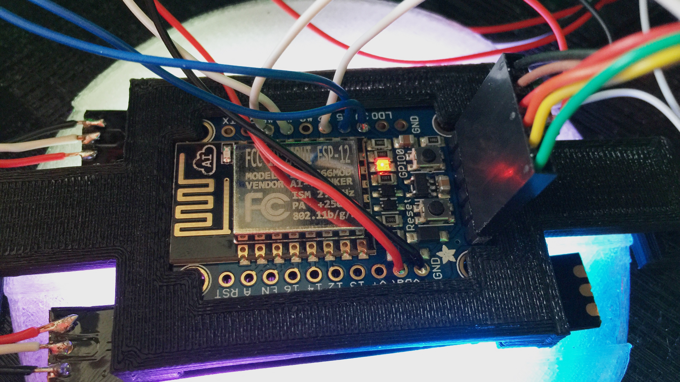
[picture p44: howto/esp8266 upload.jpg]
esp8266 upload

1. Run the `ESP_DOWNLOAD_TOOL_V2.4.exe` from the `firmware/flashtool` folder, configure the proper COM port that's assigned to the FTDI cable and program the ESP8266.

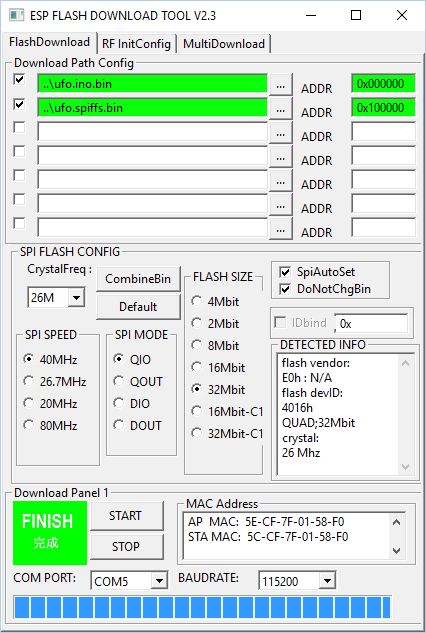
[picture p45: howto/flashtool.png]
flashtool


### Build the firmware yourself
1. Install Arduino IDE 1.6.7+ and in the Preferences dialog, type this board manager URL: `http://arduino.esp8266.com/stable/package_esp8266com_index.json`
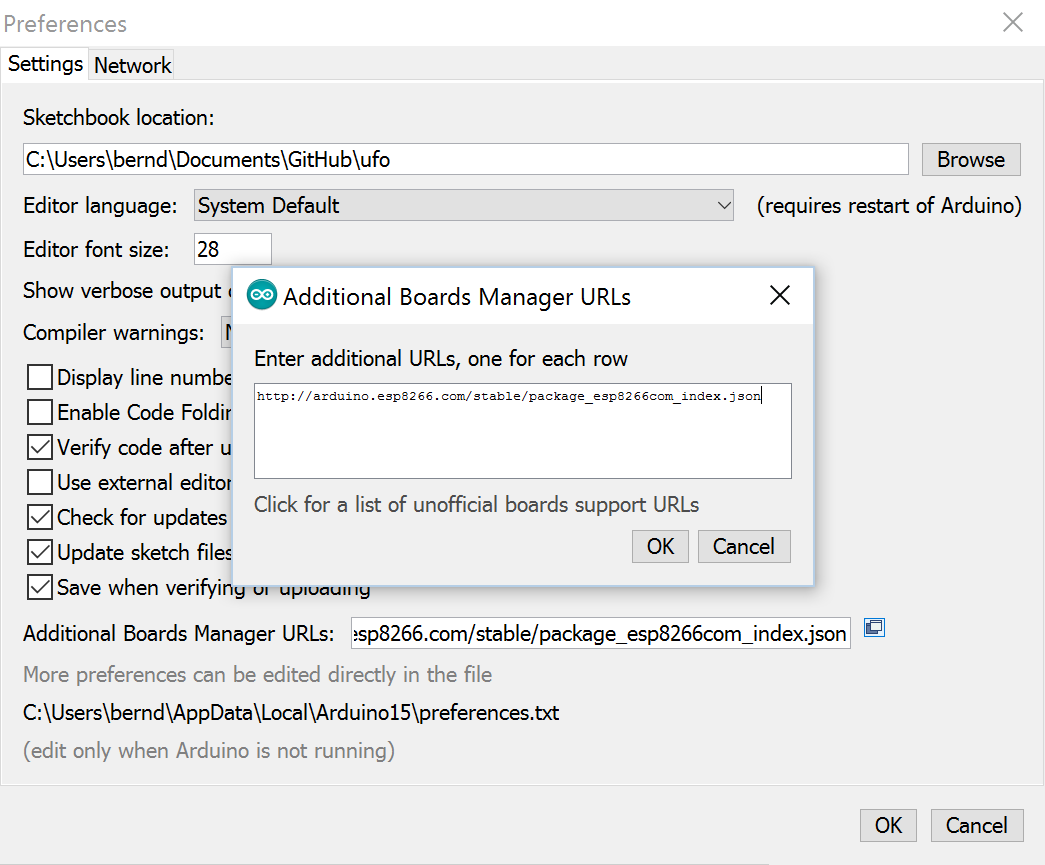
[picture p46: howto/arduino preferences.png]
Arduino IDE preferences
 Make sure to restart the IDE afterwards.
1. Install the ESP8266 board using Arduino IDE Board Manager under the Tools menu.
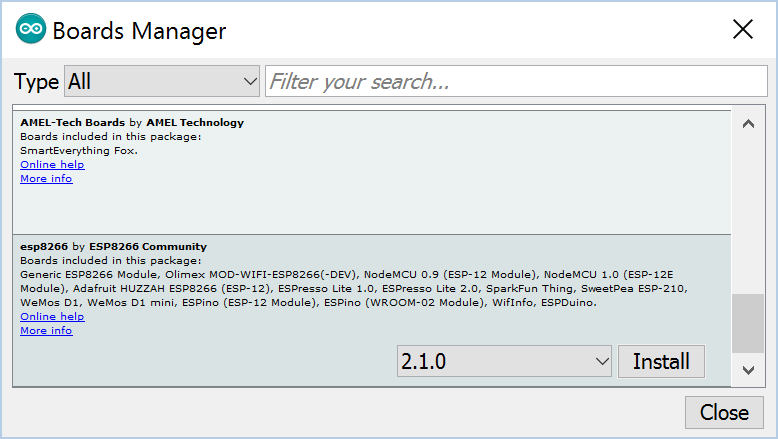
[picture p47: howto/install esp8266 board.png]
Arduino board manager

1. Configure the microcontroller in IDE
  * Adafruit Huzzah ESP8266 board
  * 3MB SPIFFS
  * serial port that's connected to the FTDI serial cable
  * USBtinyISP as Programmer
  * 115200bps
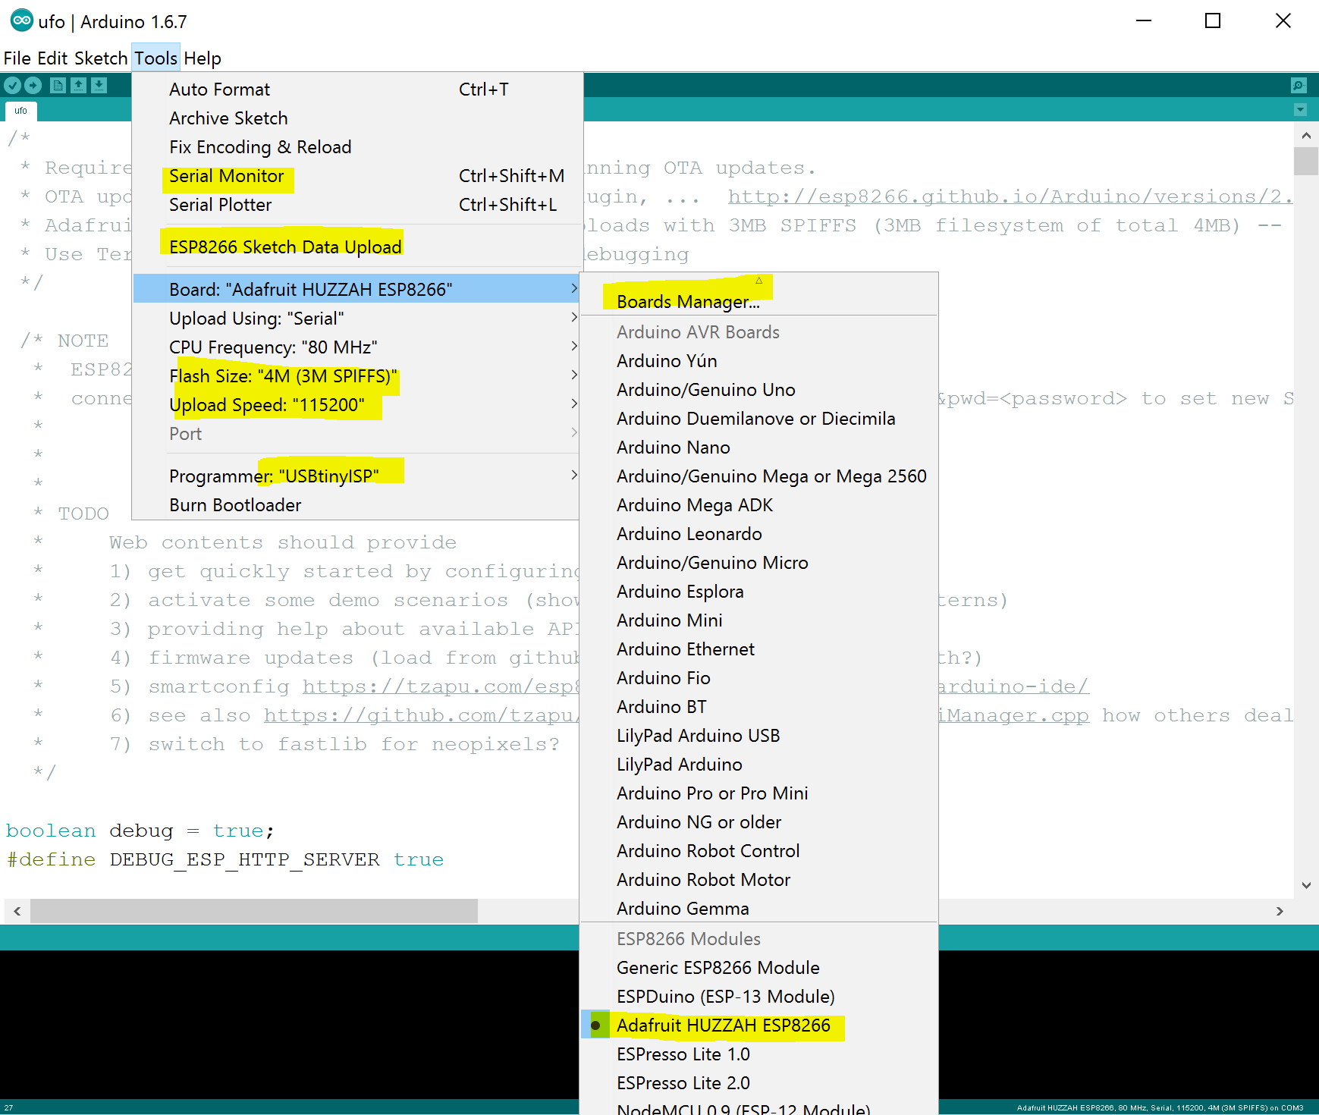
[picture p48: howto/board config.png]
board config

1. Add *Adafruit DotStar* library, needed to control the LED strips
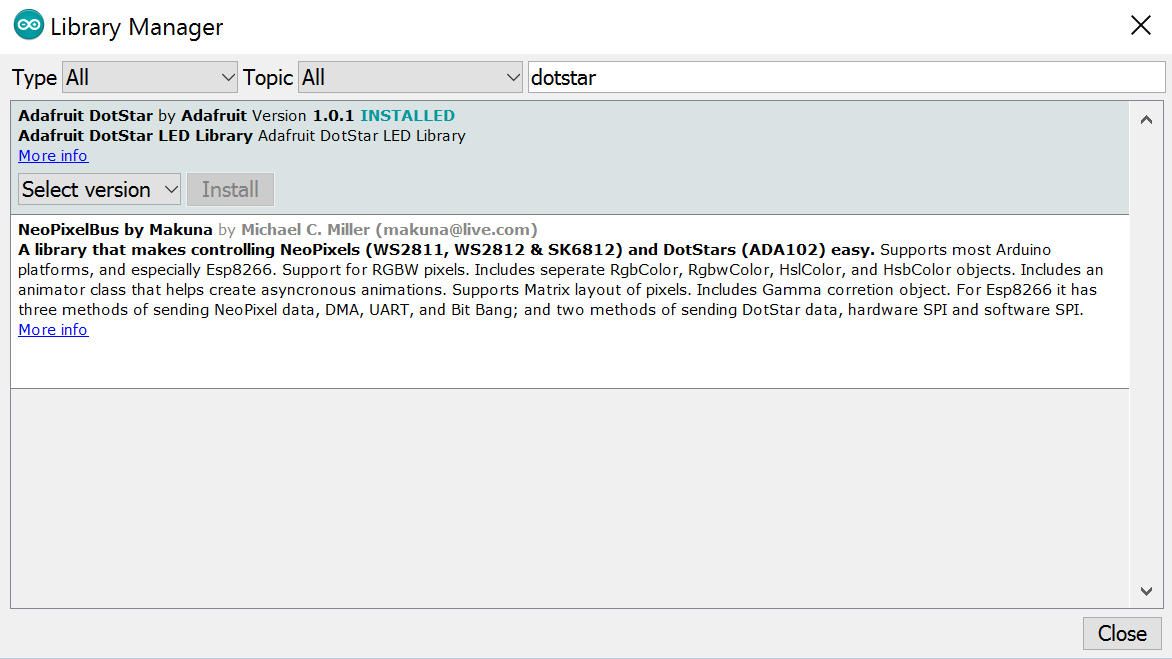
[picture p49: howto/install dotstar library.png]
dotstar library

1. Arduino JSON library
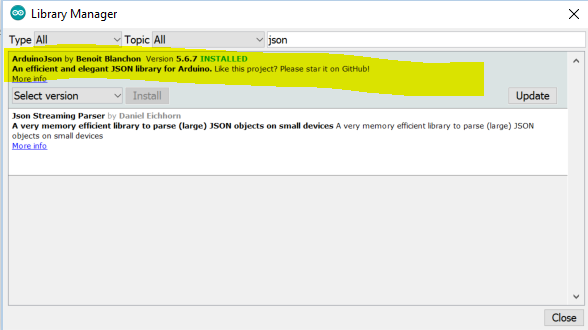
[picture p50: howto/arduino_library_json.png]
JSON library

1. Use *Tools->Serial Monitor* to see the output of the ESP8266
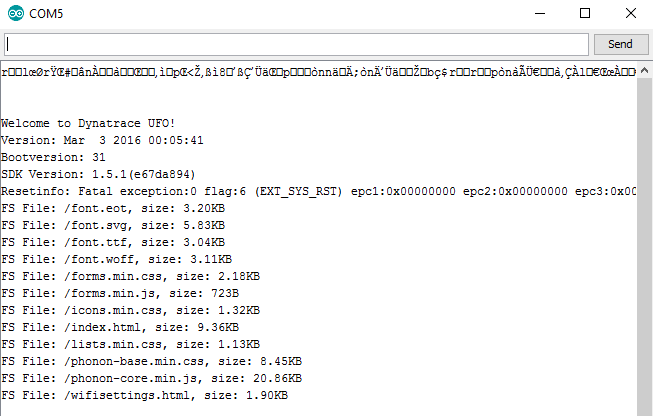
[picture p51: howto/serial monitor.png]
serial monitor

1. Open ufo.ino in Arduino IDE
1. Place the ESP8266 in firmware programming mode by pressing the buttons in the following sequence:
  * Press and hold Reset
  * Press GPIO0. You should see the red LED turn on
  * Release Reset
  * Release GPIO0 and make sure the red LED is still lit, as it's signaling that the ESP8266 expects a firmware download
1. Menu *Sketch->Upload CTRL-U* will compile and upload the sketch (firmware) via the serial interface.
Read more here: [compile and upload firmware through serial](https://learn.adafruit.com/adafruit-huzzah-esp8266-breakout/using-arduino-ide)
1. Upload the Website files to the SPIFFS file system. There are two variants to do this:
  * Option 1: Put the ESP8266 into programming mode again and upload the entire content set of the data folder through an Arduino IDE plug-in via the serial interface. To do that you have to have the ufo.ino file opened in Arduino IDE as the plugin will use the data folder relative to the opened file.
 Note that the serial monitor must be closed when using the *ESP8266 Sketch Data Upload* function from the Arduino IDE tools menu.
 Also you do need an Arduino IDE plug-in from here:
[upload file system and web site](https://github.com/esp8266/Arduino/blob/master/doc/filesystem.rst#uploading-files-to-file-system) (SPIFFS)

  * Option 2 (requires option 1 executed once to format the file system):
 (TODO: Format the ESP8266 filesystem using the WebUI or api call `/api?formatfilesystem=true`)
 and upload the all files (*.html, *.css, font.*, ...) that are contained in the `data` folder through the Web UI using the firmware upload form.
 those files will be automatically put on the ESP8266 file system.

 Note: if you want to modify the contents of the webpage, you need to regenerate WebContent.h using Convert_bin2c.py .
 For that to run you need to have Python 2.7+ installed.

## Configure the UFO
Check out the [__Quickstart guide__](../quickstart/readme.md) to configure the UFO.

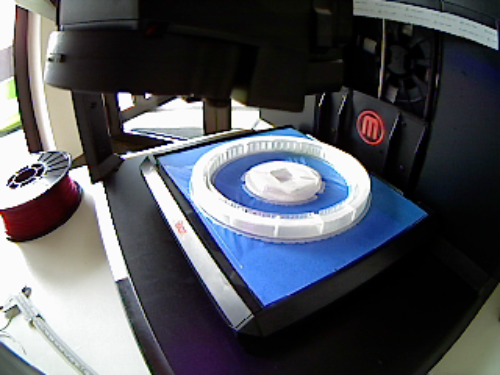
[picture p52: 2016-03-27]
3dprint/printfiles v3/ledring.png

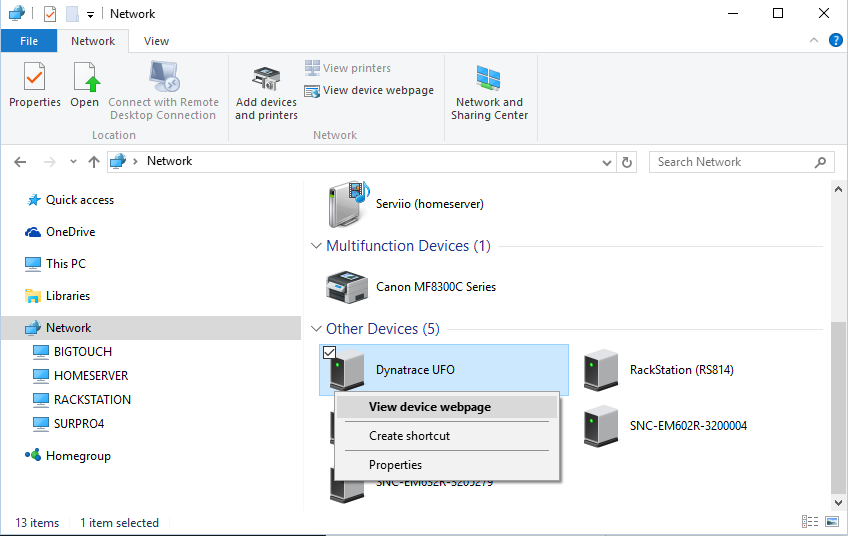
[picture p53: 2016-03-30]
howto/windows discovers ufo.png

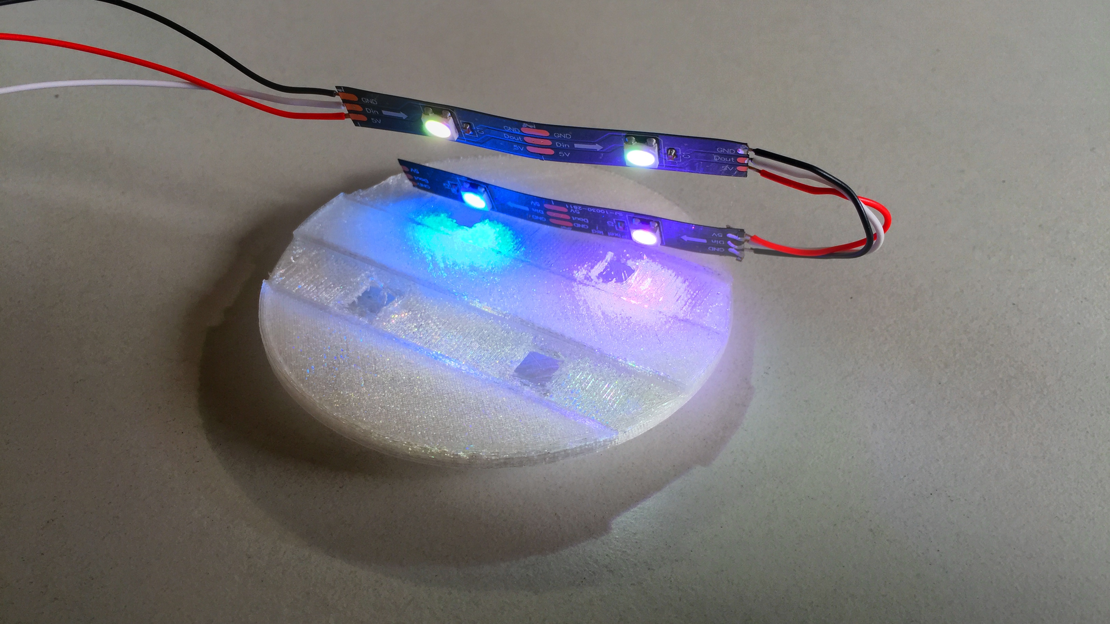
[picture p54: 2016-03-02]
howto/2x2 LEDs in series.jpg

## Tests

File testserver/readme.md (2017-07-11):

# Node.js test server
For quicker testing of changes to the web UI, use this node.js-based server. You must install Node.js and the node-static module.

### Installation
* Install Node.js (we used version 4.x)
* Delete the `node_modules` folder if it exists. Otherwise, npm install will fail
* Install the node-static web server module using `npm install node-static`

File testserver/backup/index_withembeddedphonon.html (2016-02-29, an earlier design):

# Wifi Settings

TODO: Please not this mac address for later lookup of IP address in DHCP table or for assigning a fixed IP address through DHCP Apply WIFI setting

# Dynatrace UFO

- IoT Actions
- LED Off On
- WHIRL Off On
- WHIRL COLOR R G
- Info
- Firmware update

# Info

- System
- Heap: -
- Firmware: -
- Network
- SSID: -
- IP: -
- Subnetmask: -
- Gateway: -
- DNS: -
- Hostname: -
- Macaddress: -
- Wifi autoconnect: -
- Accesspoint
- IP: -
- Connected stations: -

# Firmware upload

Select firmware file like ufo.ino.bin or index.html

- Update

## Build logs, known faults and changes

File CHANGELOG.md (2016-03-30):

Version 0.2
* switched from neopixel LED strip to DotStar LED strips, because neopixels requires blocking interrupts, what caused networking issues
* added SSDP discovery for windows (Windows File Explorer --> Network --> shows upnp devices including the UFO)

Version 0.1
* initial version using neopixels
* model prints on Ultramaker 2+ and Makerbot 5th gen

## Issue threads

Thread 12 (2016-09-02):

CAD source files for LED Ring and Separator Ring?

awk, 2016-09-02:
I noticed that the 3dprint folder has the STL files for the LED Ring and Separator Ring, but no CAD source files? It looks like the ufo.123dx files use the LED Ring as an imported STL object (i.e. a mesh)

I'd like to be able to make some tweaks to the LED Ring for my own build and have access to a CAD tool that can handle many formats - do you have an non-mesh model for the rings? In STEP, SAT, or other similar format?

flyinggorilla, 2016-09-13:
Sorry for my late reply. The 123dx file is the source file. The original design was done with Autodesk 123D what you can download yourself for free to do modifications. Btw. it would be great if you would share a picture or the like of your ufo version.

Closed 2016-09-13.

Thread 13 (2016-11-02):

request to buy a Dynatrace UFO instead of building it yourself

flyinggorilla, 2016-11-02:
If you would prefer to buy a Dynatrace UFO versus build it yourself,
then please let us know. In case we get enough requests,
we will let produce them for purchase.

Please post a comment to this issue in case you have interest to buy one.

Leviter, 2016-11-16:
I would really like to buy one...   :-)

GeorgeBark, 2016-12-12:
I would like to buy 3 or 4, depending on price :)

pragma81, 2017-01-04:
+1

flyinggorilla, 2017-01-09:
thanks for your replies, good to hear that there is demand. right now we are looking into upgrading to the ESP32 microcontroller, which allows us to provide better ease-of-use with the firmware and also better TLS and enterprise WIFI connectivity at practically no noticeable increase in cost.

the price is not finalized, but it will be in the range of 200-390 USD for a single unit. likely on the lower side in form of a package that includes multiple units and/or other offerings that are to be defined. note that we plan to produce at first a batch of 1000 pieces and the certifications eat up a lot of the cost producing it.

sounds reasonable?

ccardozas, 2017-01-09:
We could buy a few for your Operation Centers.
The price sounds pretty reasonable

Leviter, 2017-01-10:
Still very interested!

timzski01, 2017-01-28:
I would buy a few for my customers. I can see many of them buying extra.

flyinggorilla, 2017-01-29:
thanks, good to hear.
meanwhile i have some good news. you will be able to pre-order mid february. plan is to start shipping by june.

flyinggorilla, 2017-02-08:
Good news, the Dynatrace UFO is now available for pre-order. They will be produced in June and shipped in July if everything goes as planned.
[](https://www.dynatrace.com/solutions/devops/ufo/get/)

flyinggorilla, 2017-07-11:
yeah! we are now shipping the new UFOs!
video: [https://youtu.be/6z9BTHhvWSU](https://youtu.be/6z9BTHhvWSU)

flyinggorilla, 2017-07-11:
UFO order form: [https://www.dynatrace.com/solutions/devops/ufo/get/](https://www.dynatrace.com/solutions/devops/ufo/get/)

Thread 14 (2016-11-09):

multiple errors trying to compile.

billieblaze, 2016-11-09:
Trying to compile and getting multiple library related errors.   Would it be possble for you to version control any 3rd party dependencies?   I had to add ArduinoJSON first, and then i started getting errors from ESP libraries..

flyinggorilla, 2016-11-16:
Hi thanks for the note. I have added the ArduinoJSON library to the howto documentation, which lists the dependencies. For now we wont check-in third parties. We consider moving from ESP8266 to ESP32 and will reconsider how we deal with third party libraries.

Closed 2016-11-16.

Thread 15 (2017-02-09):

WIFI Security options and suggestion for "offline" mode

jpalmiero, 2017-02-09:
All,

I am not sure if this is where I would leave suggestions or not.  Andi Grabner gave me a UFO at the Perform 2017 conference and I am very excited to use it!!  I started working on it last night and I would like to make a few suggestions:

1) Only supporting WPA is sort of limiting.  You would be able to setup a personal network, but this isn't going to be something that you are going to be able to introduce in an enterprise readily.

2) I know that you guys are on the cutting edge of development, but some swagger doc for how to interact with the UFO would be great.  The only "examples" that I saw where those when you connect to the UFO (example of turning the logo on/off and example to change the top color, however, you would kind of have to reverse engineer the RESTful API to understand how to use it.)  Maybe I was looking in the wrong place.

3) It would be great if you could interact w/ it in an offline mode.  this relates back to #1 above in that I was not able to get it connected to a WIFI network last night.  It would be great if you could programmatically interact with it while it is broadcasting its own access point.  Yes, you can turn the logo on and off, however, I was not able to change to top ring color because it is in the blue blinking mode waiting to be programmed with a wireless network.  A thought would be that you could send it a command that would move it out of this mode and then you can start to build (and test) your code against it for those times when you can't get it to sync with a wireless network.

thanks,
jeff

helmut-s, 2017-02-09:
Actually we are currently working on making Enterprise WPA2 work. Unfortunately the ESP8266 which is used in the current implementation (and in your UFO) is practically not able to do it (to less resources). The next generation of UFOs would use the ESP32 which should be able to handle it. Unfortunately (again) this is not working yet and we are currently in the process of troubleshooting it.
2 and 3 are valid points and I will work on them...
If you have any questions regarding the API feel free to ask.

jpalmiero, 2017-02-09:
Helmut

Thanks a million.  Just a little constructive criticism.  It's great. Will send you the way I intend to use the UFO later on. It's going to be great.

Thanks,
Jeff

On Feb 9, 2017, at 8:34 AM, helmut-s <notifications@github.com<mailto:notifications@github.com>> wrote:

Actually we are currently working on making Enterprise WPA2 work. Unfortunately the ESP8266 which is used in the current implementation (and in your UFO) is practically not able to do it (to less resources). The next generation of UFOs would use the ESP32 which should be able to handle it. Unfortunately (again) this is not working yet and we are currently in the process of troubleshooting it.
2 and 3 are valid points and I will work on them...
If you have any questions regarding the API feel free to ask.

—
You are receiving this because you authored the thread.
Reply to this email directly, view it on GitHub<https://github.com/Dynatrace/ufo/issues/15#issuecomment-278695869>, or mute the thread<https://github.com/notifications/unsubscribe-auth/AOekRo_NFZY2GgLZLNznFFy79WSTqB9Eks5raz_9gaJpZM4L8Kqy>.

jpalmiero, 2017-02-13:
Helmut,

QQ.  I am trying to get the UFO to come up on the wireless hot spot that I start up on my iphone.  The name of the wifi network is “jeff’s iPhone” and the password is pretty involved.  When UFO reboots, it just blinks yellow and never connects.  Could it be a problem with the SSID?  Or has anyone tested connecting to a iPhone personal hot spot.

Thanks,
jeff

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

helmut-s, 2017-02-14:
@jpalmiero
Hi Jeff!

Unfortunately I do not have an iPhone to test. Using my (windows) phone with your SSID and a rather complicated password works fine. Die you test some simpler strings?
One thing I experienced from time to time is that I do not get a connection after the reboot but have to do a hard reset (power off/on) to make it work – but guess you tried that already…

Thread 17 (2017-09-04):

Troubles with LED Ring gaps

norillsa, 2017-09-04:
Hi guys - in the v3 files, the .stl for the LED ring I'm having issues getting a clean print on the Prusa i3 MK2/S printer. What I witness is a bridge strand is looped around the inner brackets and then the printer attempts to fill from edge-to-bridge. It's never worked cleanly, sometimes only filling about half-way to the bridge. As the loose strands curl, harden and lift then it interferes with the next layers (14+) and then breaks many other existing parts.

One option I'm trying is to cut/split the entire ledring model at layer 14 - printing them separately and then using some glue to put them back into place.

Any advice on the slice settings?

-mt

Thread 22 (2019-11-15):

Filter problems by Management Zone(s)

reedtdan, 2019-11-15:
Hello all,

I have a suggestion regarding customization of the problems feed. IHAC that wants to only have problems for a specific MZ within the tenant. In order to make this more flexible, the feature to filter the problem down to a set of MZ's would be useful.

If this is not in scope, the current workaround I am working on is to build an API proxy that filters the problem feed down to a set of MZ's. From what I have seen looking at DataPolling file, I am curious if I would have to make any changes on the UFO side to point to an API proxy or ingest the filtered data.

Thanks,
Dan

Closed 2020-01-09.

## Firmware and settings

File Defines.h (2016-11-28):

#define FIRMWARE_VERSION F(__DATE__ " " __TIME__)

#define DEFAULT_HOSTNAME F("ufo")
#define DEFAULT_APSSID F("ufo")

// ESP8266 Huzzah Pin usage
#define PIN_DOTSTAR_LOGO 2
#define PIN_DOTSTAR_LOWERRING 4
#define PIN_DOTSTAR_UPPERRING 5
#define PIN_DOTSTAR_CLOCK 14
#define PIN_FACTORYRESET 15

#define EEPROM_MAXSIZE 64 // max number of bytes to store in eeprom (can be up to 4k; its using one sector after the spiffs) 

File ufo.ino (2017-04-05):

/*
   Requires Arduino IDE 1.6.8 or later
   ESP8266 Arduino library v2.3.0 or later
   Adafruit Huzzah ESP8266-E12, 4MB flash, uploads with 3MB SPIFFS (3MB filesystem of total 4MB) -- note that SPIFFS upload packages up everything from the "data" folder and uploads it via serial (same procedure as uploading sketch) or OTA. however, OTA is disabled by default
   Use Termite serial terminal software for debugging

   NOTE
    ESP8266 stores last set SSID and PWD in reserved flash area
    connect to SSID huzzah, and call http://192.168.4.1/api?ssid=<ssid>&pwd=<password> to set new SSID/PASSWORD


*/
//-------------------------------------------------------------------------------------------------------------------------

boolean debug = true;

//-------------------------------------------------------------------------------------------------------------------------

//#include <ArduinoJson.h>
#include <ESP8266WiFi.h>
#include <WiFiClient.h>
#include <ESP8266WebServer.h>
#include <Wire.h>
#include <FS.h>
#include <EEPROM.h>
#include <Adafruit_DotStar.h>
#include <StreamString.h>
#include "DisplayCharter.h"
#include "MyRequestHandler.h"
#include "DataPolling.h"
#include "Config.h"
#include "defines.h"

//-------------------------------------------------------------------------------------------------------------------------

Adafruit_DotStar ledstrip_logo = Adafruit_DotStar(4, PIN_DOTSTAR_LOGO, PIN_DOTSTAR_CLOCK, DOTSTAR_BGR); //NOTE: in case the colors dont match, check out the last color order parameter
Adafruit_DotStar ledstrip_lowerring = Adafruit_DotStar(RING_LEDCOUNT, PIN_DOTSTAR_LOWERRING, PIN_DOTSTAR_CLOCK, DOTSTAR_BRG);
Adafruit_DotStar ledstrip_upperring = Adafruit_DotStar(RING_LEDCOUNT, PIN_DOTSTAR_UPPERRING, PIN_DOTSTAR_CLOCK, DOTSTAR_BRG);

DisplayCharter displayCharter_lowerring;
DisplayCharter displayCharter_upperring;

IPDisplay ipDisplay;
Config dTConfig(debug);
DataPolling dataPolling(&displayCharter_lowerring, &displayCharter_upperring, &ipDisplay, &dTConfig, debug);

boolean logo = true;

ESP8266WebServer   httpServer(80);

boolean wifiStationOK = false;
boolean wifiStationConnected = false;
unsigned int connectedCount = 0;
boolean wifiAPisConnected = false;
boolean wifiConfigMode = true;
boolean httpClientMode = false;



//-------------------------------------------------------------------------------------------------------------------------

//format bytes
String formatBytes(size_t bytes) {
  if (bytes < 1024) {
    return String(bytes) + "B";
  } else if (bytes < (1024 * 1024)) {
    return String(bytes / 1024.0) + "KB";
  } else if (bytes < (1024 * 1024 * 1024)) {
    return String(bytes / 1024.0 / 1024.0) + "MB";
  } else {
    return String(bytes / 1024.0 / 1024.0 / 1024.0) + "GB";
  }
}

// Handle Factory reset and enable Access Point mode to enable configuration
// *********TODO ********************************** DIFFERENTIATE LONG PRESS (reset all!) VS SHORT PRESS (exit client only mode to enable back website)
void handleFactoryReset() {
  if (digitalRead(PIN_FACTORYRESET)) {
    if (millis() < 10000) {  // ignore reset button during first 10 seconds of reboot to avoid looping resets due to fast booting of ESP8266
      return;
    }

    if (debug) {
      Serial.println(F("*********FACTORYRESET***********"));
      //WiFi.printDiag(Serial);
    }

    //disable dynatrace polling mode - otherwise the IP display wont be visible
    dTConfig.enabled = false;
    dTConfig.Write();
    
    WiFi.disconnect(false); //disconnect and disable station mode; delete old config
    // default IP address for Access Point is 192.168.4.1
    //WiFi.softAPConfig(IPAddress(192,168,4,1), IPAddress(192,168,4,1), IPAddress(255,255,255,0)); // IP, gateway, netmask -- NOT STORED TO FLASH!!
    WiFi.softAP(String(DEFAULT_APSSID).c_str()); // default is open Wifi

    // reset eeprom to default hostname
    eepromSet(DEFAULT_HOSTNAME);

    //WiFi.mode(WIFI_AP);
    if (debug) {
      Serial.println(String(F("Wifi reset to SSID: ")) + WiFi.SSID() + String(F(" pass: ")) + WiFi.psk());
      Serial.print(F("Wifi config mode enabled: Access point enabled at open Wifi SSID: "));
      Serial.println(DEFAULT_APSSID);
      Serial.println(F("Restarting...."));
      //WiFi.printDiag(Serial);
      Serial.flush();
    }
    ESP.restart();

  }
}

void WiFiEvent(WiFiEvent_t event) {
    switch (event) {
      case WIFI_EVENT_STAMODE_GOT_IP:
        if (debug) Serial.println(String(F("WiFi connected. IP address: ")) + String(WiFi.localIP().toString()) + String(F(" hostname: ")) + WiFi.hostname() + String(F("  SSID: ")) + WiFi.SSID());
        wifiStationOK = true;
        ipDisplay.ShowIp(WiFi.localIP().toString(), &displayCharter_lowerring);
        break;
      case WIFI_EVENT_STAMODE_DISCONNECTED:
        if (debug) Serial.println(F("WiFi client lost connection"));
        wifiStationOK = false;
        wifiStationConnected = false;
        break;
      case WIFI_EVENT_STAMODE_CONNECTED:
        if (debug) Serial.println(F("WiFi client connected"));
        wifiStationConnected = true;
        connectedCount = 0;
        break;
      case WIFI_EVENT_STAMODE_AUTHMODE_CHANGE:
        if (debug) Serial.println(F("WiFi client authentication mode changed."));
        break;
      //case WIFI_STAMODE_DHCP_TIMEOUT:                             THIS IS A NEW CONSTANT ENABLE WITH D SDK
      //  Serial.println("WiFi client DHCP timeout reached.");
      //break;
      case WIFI_EVENT_SOFTAPMODE_STACONNECTED:
        if (debug) Serial.println(String(F("WiFi accesspoint: new client connected. Clients: "))  + String(WiFi.softAPgetStationNum()));
        if (WiFi.softAPgetStationNum() > 0) {
          wifiAPisConnected = true;
        }
        break;
      case WIFI_EVENT_SOFTAPMODE_STADISCONNECTED:
        if (debug) Serial.println(String(F("WiFi accesspoint: client disconnected. Clients: ")) + String(WiFi.softAPgetStationNum()));
        if (WiFi.softAPgetStationNum() > 0) {
          wifiAPisConnected = true;
        } else {
          wifiAPisConnected = false;
        }
        break;
      case WIFI_EVENT_SOFTAPMODE_PROBEREQRECVED:
        //Serial.println("WiFi accesspoint: probe request received.");
        break;
    }
  
}

void printSpiffsContents() {
  if (debug)
  {
    Dir dir = SPIFFS.openDir(F("/"));
    while (dir.next()) {
      String fileName = dir.fileName();
      size_t fileSize = dir.fileSize();
      Serial.printf(String(F("FS File: %s, size: %s\n")).c_str(), fileName.c_str(), formatBytes(fileSize).c_str());
    }
    Serial.printf("\n");
  }
}

void setupSerial() {
  // checking availability of serial connection
  int serialtimeout = 5000; //ms
  Serial.begin ( 115200 );
  while (!Serial) {
    if (serialtimeout > 0) {
      //serialtimeout -= 50;
    } else {
      debug = false;
      break;
    }
    delay(50);
  }

  if (debug) {
    Serial.println(F(""));
    Serial.println(F(""));
    Serial.println(F(""));
    Serial.println(F("Welcome to Dynatrace UFO!"));
    Serial.print(F("UFO Firmware Version: "));
    Serial.println(FIRMWARE_VERSION);
    Serial.println(String(F("ESP8266 Bootversion: ")) + String(ESP.getBootVersion()));
    Serial.println(String(F("ESP8266 SDK Version: ")) + String(ESP.getSdkVersion()));
    Serial.println(String(F("Resetinfo: ")) + ESP.getResetInfo());
  }
}


String eepromRead() {
  //EEPROM access to retreive the hostname
  EEPROM.begin(EEPROM_MAXSIZE); // note this allocates a buffer in RAM
  int address = 0;
  //char eepromcontent[EEPROM_MAXSIZE]; 
  String eepromcontent;
  while (address < EEPROM_MAXSIZE) {
    char val = EEPROM.read(address);
    //eepromcontent[address] = val;
    if (!val) {
      break;
    }
    eepromcontent += val;
    address++;
  }

  if (debug) {
    Serial.println("EEPROM bytes: " + String(address) + " data: " + eepromcontent);
  }

  if (address >= EEPROM_MAXSIZE) { // no term zero found, so reset the EEPROM to the default
    EEPROM.write(0, 'u');
    EEPROM.write(1, 'f');
    EEPROM.write(2, 'o');
    for (address = 3; address < EEPROM_MAXSIZE; address++) {
      EEPROM.write(address, 0); 
    }
    eepromcontent = "";
  } 
  EEPROM.end(); // commits EEPROM contents to flash if changed/written; releases allocated memory
  return eepromcontent;
}    


void eepromSet(String content) {
  EEPROM.begin(EEPROM_MAXSIZE); // note this allocates a buffer in RAM

  // write string content
  int len = content.length();
  if (len >= EEPROM_MAXSIZE) {
    len = EEPROM_MAXSIZE-1;
  }
  int addr = 0;
  while (addr < len) {
    EEPROM.write(addr, content.charAt(addr));
    addr++;
  }

  // fill the remaining eeprom buffer with zeros
  while (addr < EEPROM_MAXSIZE) {
    EEPROM.write(addr, 0);
    addr++;
  }
  EEPROM.end(); // commits EEPROM contents to flash if changed/written; releases allocated memory
}    



// initialization routines
void setup ( void ) {
  setupSerial();

  pinMode(PIN_FACTORYRESET, INPUT); //, INPUT_PULLUP); use INPUT_PULLUP in case we put reset to ground; currently reset is doing a 3V signal

  ledsSetup();

  String hostname = eepromRead(); // retrieves the hostname  ; DEFAULT_HOSTNAME

  // initialize ESP8266 file system
  SPIFFS.begin();
  printSpiffsContents();

  // load non-wifi config from SPIFFS config.json file
  if (dTConfig.Read()) {
    if (debug) Serial.println(String(F("Dynatrace envid: ")) + dTConfig.dynatraceEnvironmentID + String(F(" apikey: ")) + dTConfig.dynatraceApiKey);
  } else {
    if (debug) Serial.println(F("Loading Dynatrace config failed!"));
  }

  // initialize Wifi based on stored config
  WiFi.onEvent(WiFiEvent);
  WiFi.hostname(hostname); // note, the hostname is not persisted in the ESP config like the SSID. so it needs to be set every time WiFi is started
  wifiConfigMode = WiFi.getMode() & WIFI_AP;

  if (debug) {
    Serial.println(String(F("Connecting to Wifi SSID: ")) + WiFi.SSID() + String(F(" as host ")) + WiFi.hostname());
    if (wifiConfigMode) {
      Serial.println(String(F("WiFi Configuration Mode - Access Point IP address: ")) + WiFi.softAPIP().toString());
    }
    //WiFi.printDiag(Serial);
  }

  httpServer.addHandler(new MyFunctionRequestHandler(&displayCharter_lowerring, &displayCharter_upperring, &ipDisplay, &ledstrip_logo, &dTConfig, debug));
  httpServer.begin();

}

unsigned int tick = 0;
unsigned long startMillis = millis();

void loop ( void ) {

  tick++;

  handleFactoryReset();

  if (!wifiConfigMode && wifiStationOK){
    unsigned long m = millis();
    if (m - startMillis > dTConfig.pollingIntervalS * 1000){
      startMillis = m;
      dataPolling.Poll();
    }
    ipDisplay.ProcessTick();   
  }
  
  httpServer.handleClient();

 
  displayCharter_lowerring.Display(ledstrip_lowerring);
  displayCharter_upperring.Display(ledstrip_upperring);
  
  yield();

  // show AP mode in blue to tell user to configure WIFI; especially after RESET
  // blinking alternatively in blue when no client is connected to AP;
  // binking both rings in blue when at least one client is connected to AP
  if (wifiConfigMode) {
    // AG-04-05-2017: if a client is connected do no longer show the blue lights - that prevents the Demo Use Case when somebody connects to the "ufo" hotspot and changes colors
    if (wifiAPisConnected) {
      
    }
    /*if (wifiAPisConnected && (tick % 500 > 200)) {
      dotstarSetColor(ledstrip_upperring, 0, 0, 255);
      dotstarSetColor(ledstrip_lowerring, 0, 0, 255);
    }*/ else {
      if (tick % 1000 > 500) {
        dotstarSetColor(ledstrip_upperring, 0, 0, 255);
        dotstarSetColor(ledstrip_lowerring, 0, 0, 0);
      } else {
        dotstarSetColor(ledstrip_lowerring, 0, 0, 255);
        dotstarSetColor(ledstrip_upperring, 0, 0, 0);
      }
    }
  } else { // blink yellow while not connected to wifi when it should
    if (!wifiStationOK)
    {
      unsigned int i = tick % 500;
      if (!i)
      {
        if (wifiStationConnected && (++connectedCount >= 50))
        {
          if (debug) Serial.println(F("Could not get IP - restarting!"));
          ESP.restart();
        }
      }
      else if  (i > 375)
      {
        dotstarSetColor(ledstrip_upperring, 255, 200, 0);
        dotstarSetColor(ledstrip_lowerring, 255, 200, 0);
      }
    }
  }

  yield();
  ledstrip_logo.show();
  ledstrip_upperring.show();
  ledstrip_lowerring.show();
  
}

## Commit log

2016-02-23 added 3d printing files - includes known issues
    known issues: ruxit logo needs centering, huzzah-holder clip needs to reverse claws, reset button holder needs to be added; for better printing maybe some roofs and floors may need to be increased from 1mm to a higher thickness
    [transparent.ring.v1.stl]
2016-02-23 first printout on makerbot - it needs 5 prints to cover all parts
    [bottombuildup.stl, cablestabilizer.stl, huzzahbase.stl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]
2016-02-24 update all
    [bottombuildup.stl, cablestabilizer.stl, huzzahbase.stl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]
2016-02-24 before preparing clip to mini button holder
2016-02-24 created clip for minibutton
    [minibuttonclip.stl]
2016-02-24 finalized minibutton, increased bottom thickness, increased logoinlay thickness
    logoinlay thickness 1mm --> 1.5mm; bottom thickness 1mm --> 1.5mm
    [bottombuildup.stl, logoinlay.stl, minibuttonclip.stl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]
2016-02-25 finalize v2 models
    [huzzahbase.stl, huzzahclip.stl, top.stl]
2016-02-28 added link to good 3d print guide
2016-02-28 updates to makerbot prints
2016-02-28 major update of sketch plus embedding webpage into arduino code
2016-03-01 redirect after upload + put in AP mode only after factory-reset
    [ufo.ino]
2016-03-03 howto add images
    [cablestabilizer.stl, downlightinlay.stl, ledring.stl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]
2016-03-04 updated print guide
2016-03-05 arduino ide screenshots
2016-03-05 arduino ide explanations
2016-03-05 add flash tool
    [ESP8266_RF_init.xls, MAC_TABLE.CSV, tool_config.txt]
2016-03-05 initial firmware as precompiled binary - including spiffs
    [tool_config.txt]
2016-03-06 cleanup 3d print files
    [bottombuildup.stl, cablestabilizer.stl, downlightinlay.stl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]
2016-03-06 flashtool tested
    [MAC_TABLE.CSV]
2016-03-06 updated flashtool settings
    [MAC_TABLE.CSV, tool_config.txt]
2016-03-07 add printed ufo pic
2016-03-07 bottom is now only 1.0mm instead of 1.7mm thick - made it easier to add remove transparent rings with led strips in place
    [bottombuildup.stl, cablestabilizer 4.5mm.stl, cablestabilizer 5.0mm.stl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]
2016-03-08 completed printfiles v3 fileset
    [bottombuildup.stl, cablestabilizer.stl, downlightinlay.stl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]
2016-03-08 added explosion diagram - fixed cablestabilizer 5.5mm
2016-03-08 reduced top from 1.7mm to 1.0mm --- avoid warping on makerbot
    [top.stl]
2016-03-09 added wiring sketch
    [ufo wiring sketch.fzz]
2016-03-09 fixed text
    [ufo wiring sketch.fzz]
2016-03-30 implemented DotStar LED strips. update a few howtos but still more to do
2016-04-03 fixed color order - the dotstars we use dont do RGB, they do BRG
    [ufo.ino]
2016-04-04 updated fritzing diagram with 4 pin dotstar wiring
    [ufo wiring sketch.fzz]
2016-04-04 updated phonon framework to v1.2.4 plus ruxit settings form
2016-04-05 updated fritzing file
    [ufo wiring sketch.fzz]
2016-04-06 testing ruxit integration - fixed HTTPS call --- still stack crash issue present
    [ufo.ino]
2016-04-13 comment fixes; httpclient poll interval fix - now 1 minute
    [ufo.ino]
2016-04-18 upgraded to ESP8266 Arduino library v2.2.0
2016-04-19 fix wifi config not applied properly
    [ufo.ino]
2016-04-19 moved some literals to flash - added fingerprint to SSL connection
2016-04-19 fixed event issue when not in debug mode
    [ufo.ino]
2016-04-19 Revert "fixed event issue when not in debug mode"
    This reverts commit ef704c42bd27aefe7f2b89022dab9155ebc11a4d.
    [ufo.ino]
2016-04-19 fixed improper debug switch
    [ufo.ino]
2016-10-03 New led api
2016-10-08 added ip address LED encoding info to HTML page
2016-10-12 refactoring for readability + fixing Dynatrace integration and config file
    [DisplayCharter.cpp, config.ino, leds.ino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]
2016-10-18 Make SSL connection work reliably
    free up memory to stabilize SSL
    [DisplayCharter.cpp, config.ino, ufo.ino]
2017-03-16 Update SSL FIngerprint
2017-04-05 Enable usage in WiFi Connect Mode
    When connected to the "ufo" WiFi you are now able to change the LEDs.
    Previously you could not change them - LEDs were always showing blue
2018-01-30 Update READMEs
    - Fixed links
    - Fixed typos
    - Closed minor gaps in the how-to
    - added link to REST API documentation
    - added link to https://www.exp-tech.de/ (good shop in Germany which has all the required parts for a good price)
2018-01-30 Update READMEs
    - fix https://www.exp-tech.de/ link
2019-02-12 add warranty information for 3d-printed version
